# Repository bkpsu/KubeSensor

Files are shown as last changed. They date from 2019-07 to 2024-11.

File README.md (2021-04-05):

# KubeSensor
Kube - A modular, expandable home automation multi sensor platform

## Description

The Kube V2 builds on the previous [design](https://www.thingiverse.com/thing:2539897), incorporating improvements to modularity, support for additional sensors, and building ease.

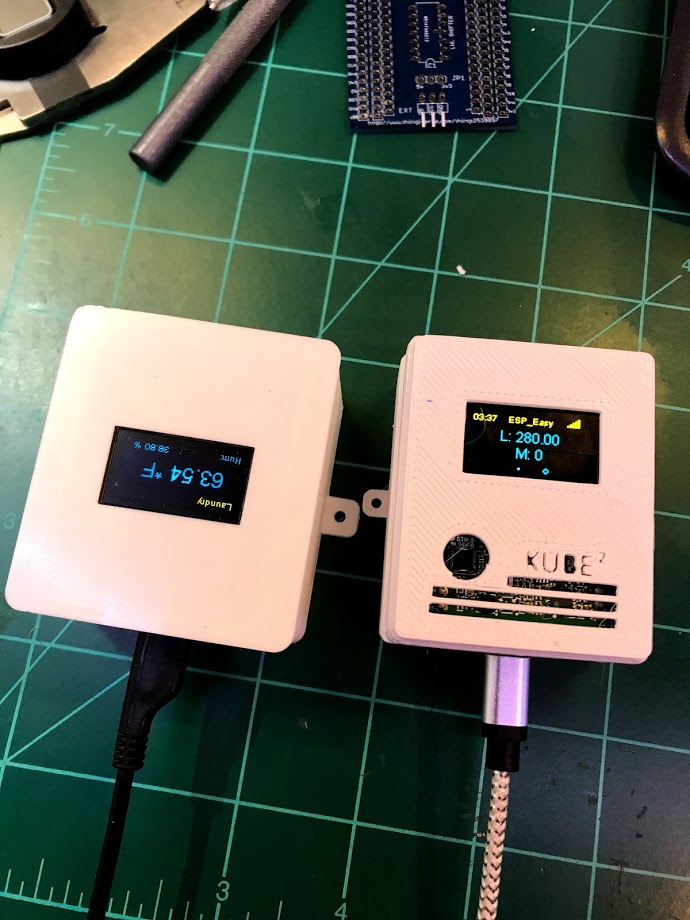
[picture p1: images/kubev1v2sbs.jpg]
    

##### Original Kube (left) and Kube V2 (right)

The main design improvement for Kube V2 is that all components are installed on dedicated PCBs, removing the need for wiring, and the PCBs are connected to each other via long headers, which allow the different "modules" to snap together to form a complete Kube.

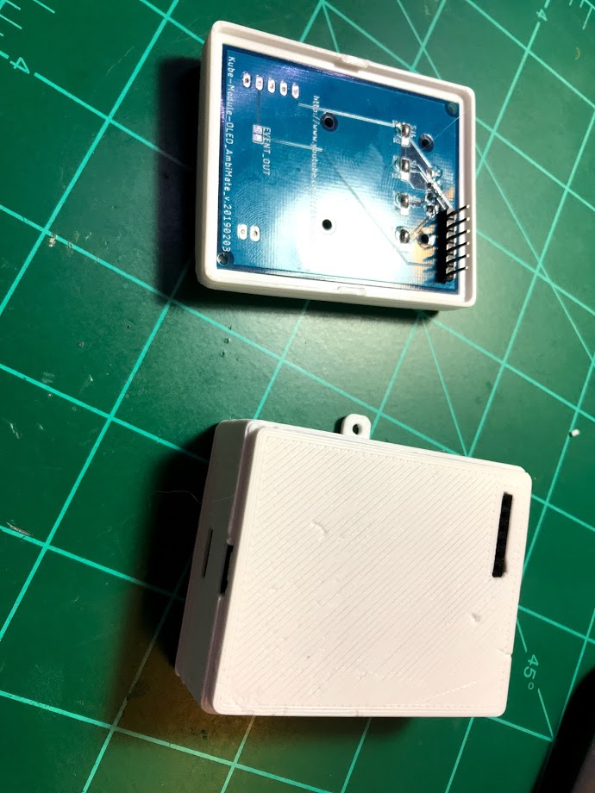
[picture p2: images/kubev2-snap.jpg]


##### OLED module (top) with male headers that snap into the base board (bottom) with tabs on the 3d printed enclosures holding the module in place

The 6-pin header is populated with I2C signals from the NodeMCU (D1/D2), D4 pin for LED control, and 5V and 3V3 power supply pins with ground. This allows building various different designs of the "stack", and future expansion of the Kube platform, via I2C connected "submodules". The design currently contains four modules, including:

1. Base module (with NodeMCU, breakout headers, 74HCT125N level shifter and external connectors/spots for DHT22 sensor)
2. Power Supply module (with AC/DC, DC/DC and POE-level power supply options, to provide the 5V power for the stack)
3. Analog/Digital IO module (offering expansion of Digital I/O up to 128 signals and 4 channels of 16-bit ADC analog)
4. OLED/AmbiMate sensor module (offering a 0.96" OLED screen for local sensor data display and support for the multiple sensor AmbiMate MS4 board from TE Connectivity)

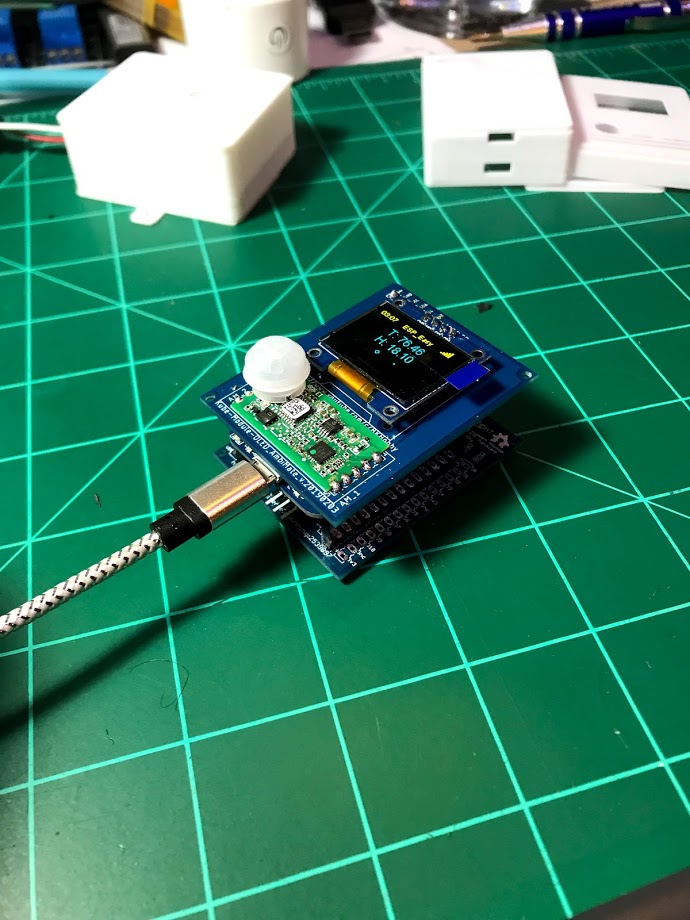
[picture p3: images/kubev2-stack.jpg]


##### Kube stack with boards 1 (Base Module) and 4 (OLED/AmbiMate) shown, comprising a multi sensor

The different boards can be stacked in any order (with OLED board on top, of course), and multiple ADIO boards can be stacked together to expand I/O up to 128 channels.

The Kube v2 supports typical ESP8266 firmwares, including [ESPEasy](https://www.letscontrolit.com/wiki/index.php?title=ESPEasy), as well as my original Kube [firmware](https://github.com/bkpsu/NodeMCU-Home-Automation-Sensor) (with minor changes for pin layout). With ESPEasy, the different sensors and OLED screen can be easily connected to home automation platofrms like [openHAB](https://www.openhab.org) or [HomeAssistant](https://www.home-assistant.io/) via MQTT.

---

## Boards

This section will describe the currently available Kube module boards in detail, including schematics and any jumper settings required for each board, as well as links to the parts required to build each module.

### 1. Kube Base Module

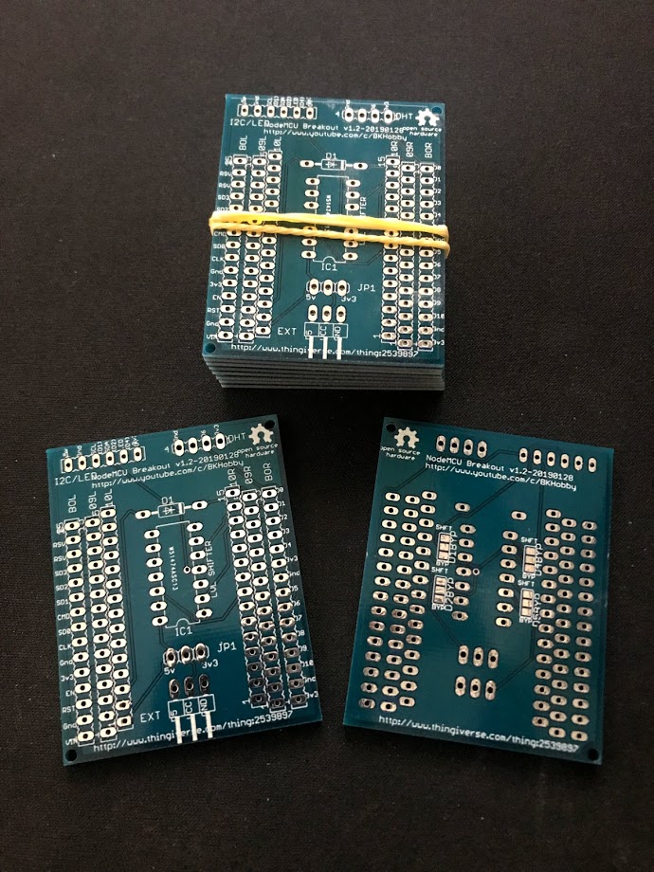
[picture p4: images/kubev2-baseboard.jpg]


The Kube Base module is the only **required** board in the Kube stack. It contains the headers for a [NodeMCU](https://amzn.to/2l9GGET) v0.9, v2 (LoLin v3 works, but won't fit the enclosure), as well as breakout headers for all of the NodeMCU pins. With just the Kube Base module, a NodeMCU, a DHT22 sensor, and an OLED screen, you can create [this sensor](https://www.thingiverse.com/thing:2539897):

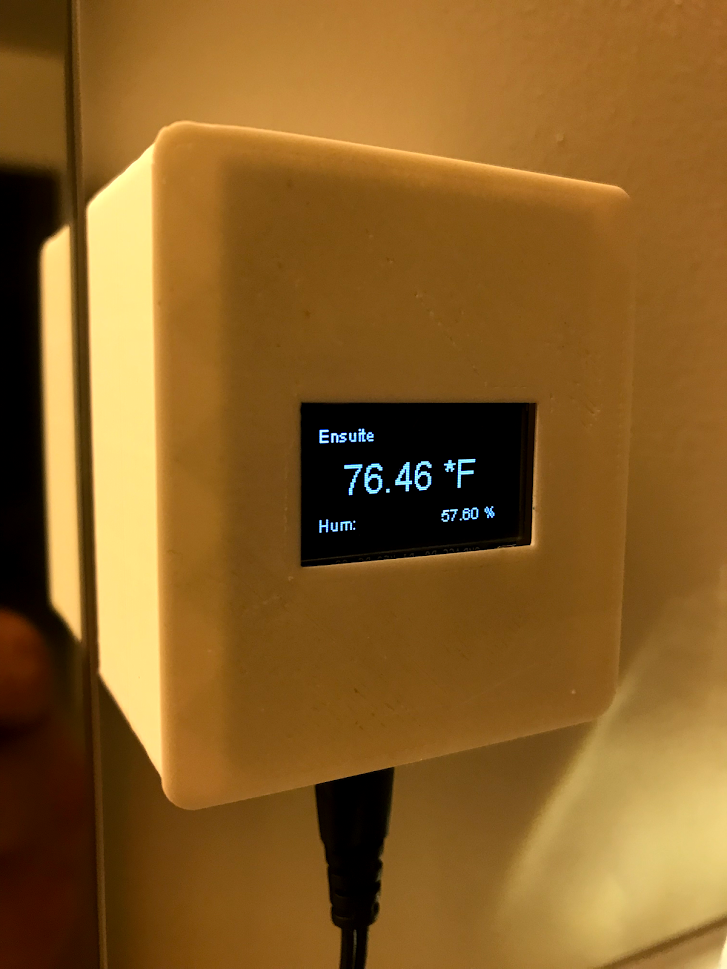
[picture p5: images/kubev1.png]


The base module contains the following features/headers:

**TOP**: (NodeMCU side)

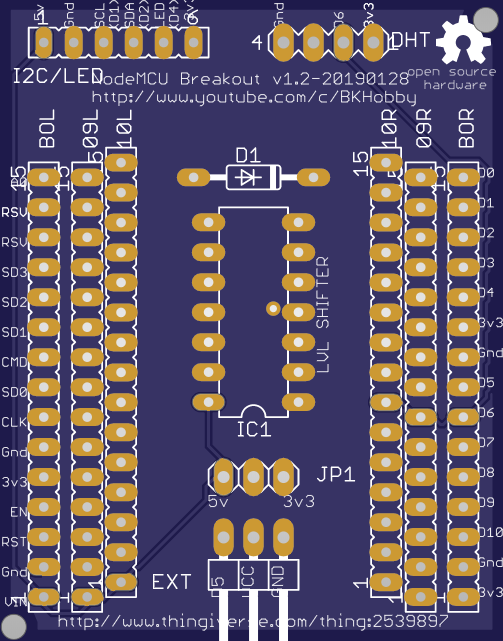
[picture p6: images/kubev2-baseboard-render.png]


|Device|Usage|Notes|
|:---|:-----|---|
|EXT|Used for external sensor connections, e.g. [HC-SR501](https://amzn.to/2l9G0zl) PIR motion sensor (D5 NodeMCU pin)|VCC pin is tied to JP1, sourcing either 3.3V or 5V DC|
|JP1|Selects 5V or 3.3V supply voltage for the EXT header|Does *not* affect D5 pin voltage range|
|IC1|[74HCT125N](https://amzn.to/2l9FBwP) 4-channel fast level shifter|Used for I2C/LED and EXT signal pins; Great for LED pixels|
|D1|[BAT43](https://amzn.to/2jFCRqv) Schottky Diode|Used between RST and D0 pins on the NodeMCU to prevent boot-up issues during flashing|
|DHT|[DHT22](https://amzn.to/2l98yZL) Temperature/Humidity sensor|Used when base baord is used as a remote temperature/humidity sensor; uses D6 pin on NodeMCU|
|I2C/LED|I2C bus connector header, to allow *daughter-boards* to connect to the Kube base board and to each other|Has both 5V and 3.3V pins, GND, SCL (D1) and SDA (D2), as well as an additional digital I/O pin (D4), commonly used in LED strip controller firmware|

**BOTTOM**:

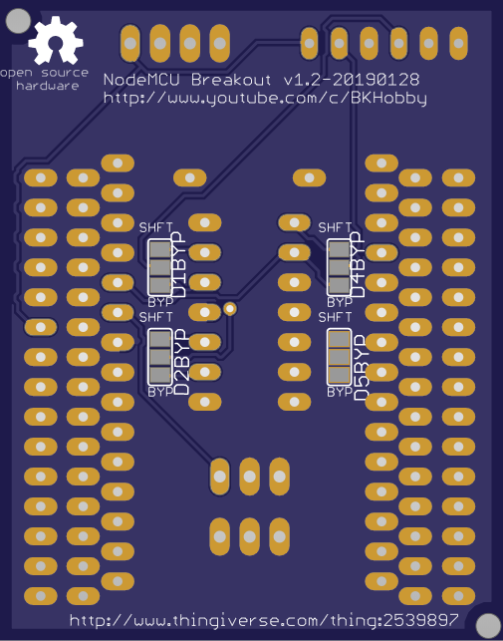
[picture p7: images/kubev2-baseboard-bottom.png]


|Device|Usage|Notes|
|:---|:-----|---|
|D1BYP, D2BYP|Used to shift (to 5V via IC1) or bypass (3.3V from the NodeMCU) the I2C Clock (D1, SCL) and Data (D2, SDA) pins within the I2C/LED header|Solder middle pad to either the SHFT (for 5V) or BYP (for 3.3v) pads.|
|D4BYP|Used to shift (to 5V via IC1) or bypass (3.3V from the NodeMCU) the D4 LED pin within the I2C/LED header|Solder middle pad to either the SHFT (for 5V) or BYP (for 3.3v) pads.|
|D5BYP|Used to shift (to 5V via IC1) or bypass (3.3V from the NodeMCU) the D5 EXT pin within the EXT sensor header|Solder middle pad to either the SHFT (for 5V) or BYP (for 3.3v) pads.|

The full schematic for the Kube baseboard is shown below: 

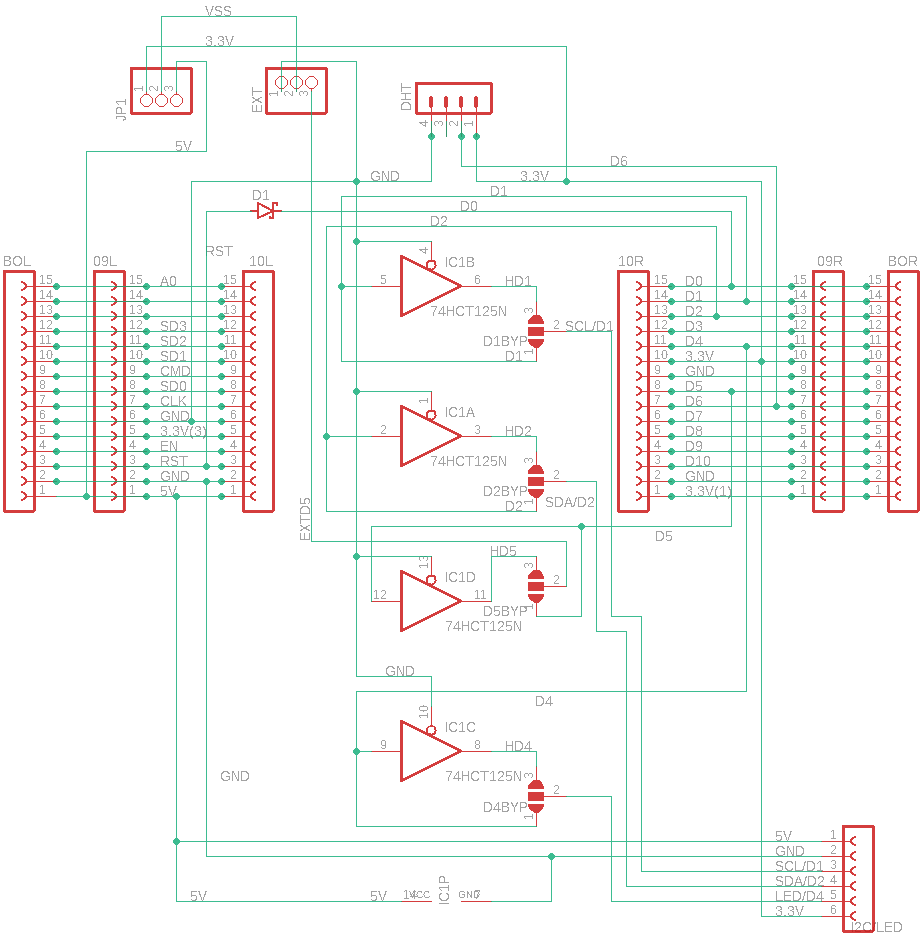
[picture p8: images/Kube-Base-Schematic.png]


### 2. Power Supply Module

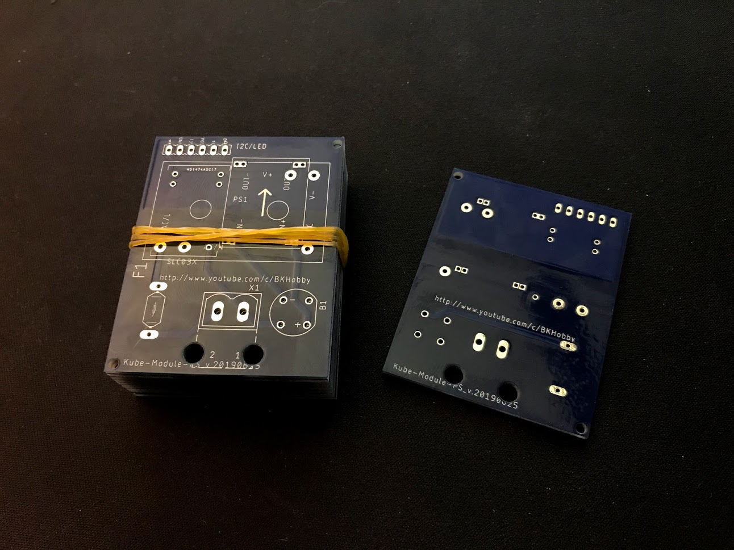
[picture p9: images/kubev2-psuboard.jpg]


The Kube Power supply submodule offers several options to provide the 5VDC power required to run the NodeMCU and the entire Kube stack. It is *generally* not required, since it's perfectly fine to power the Kube with just a USB power supply via the NodeMCU's micro-USB port (accessible via a hole in the base module's enclosure), but if you're going to use more sensors, IO boards, or other external devices, it *is recommended* to supply power to the Kube stack via this PSU board module.

The Kube PS board module provides three possible configurations, each allowing different input voltages, with 5V DC output.

1. Using a [MeanWell IRM-03-5](https://amzn.to/2lbSsym) AC/DC power supply (110VAC in, 5VDC out) for a wall-pluggable unit
2. Using [MeanWell SLC03x](https://www.arrow.com/en/products/slc03b-05/mean-well-enterprises) series DC-DC power supplies for multiple input options (12j/24VDC, Power-over-Ethernet, etc)
3. Using a [Rectifier](https://amzn.to/2lin9SL) and a [Buck Converter](https://amzn.to/2lkQhZH) to convert low-voltage AC (e.g. a door bell transformer or HVAC thermostat power) to power the kube stack.

***NOTE***: **BE EXTREMELY CAREFUL WHEN USING THE KUBE PS MODULE WITH AC POWER. THE PCB TRACES ON THE BOTTOM OF THE BOARD WILL HAVE LIVE AC VOLTAGE ON THEM. IT IS BEST TO KEEP THE UNIT UNPLUGGED WHILE ASSEMBLING/DISSASEMBLING THE KUBE STACK.**

Regardless of which of the 3 power methods you're using, the power input wiring will go through the [2-pin screw terminal](https://amzn.to/2lhCMtC) (X1), with Line or DC+ on the left terminal, and Neutral or DC- on the right terminal. The line/DC+ line is [fuse-protected](https://amzn.to/2jPolfY) prior to going to the power supplies. Secure the input wiring with a zip-tie through the two holes drilled below the X1 connector.

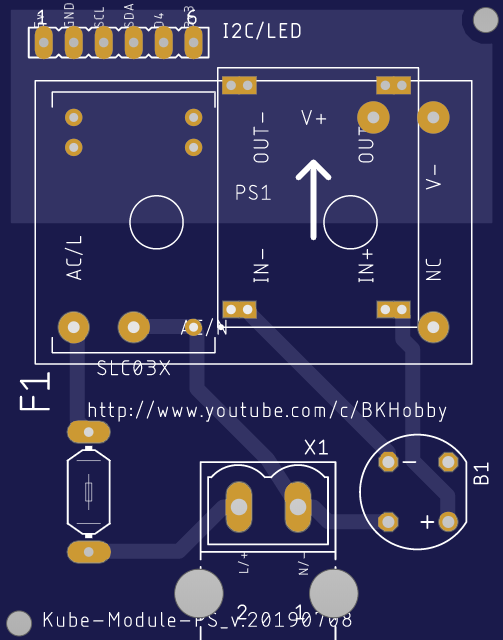
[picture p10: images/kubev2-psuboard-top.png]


The full schematic for the Kube Power Supply submodule is shown below:

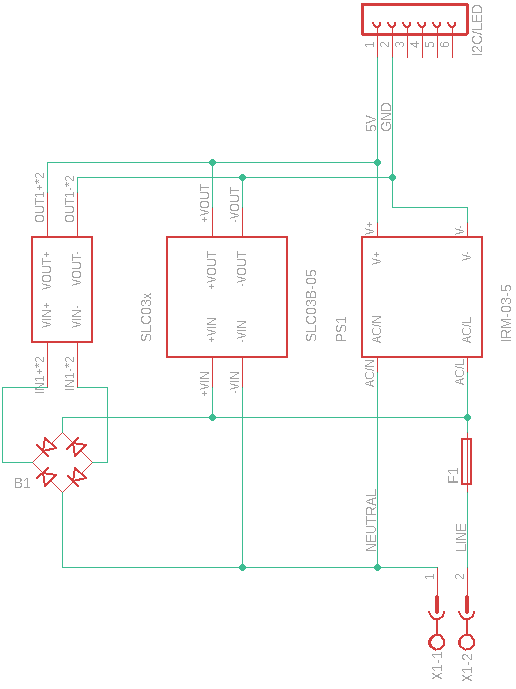
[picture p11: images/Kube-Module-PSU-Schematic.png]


### 3. Analog/Digital I/O module

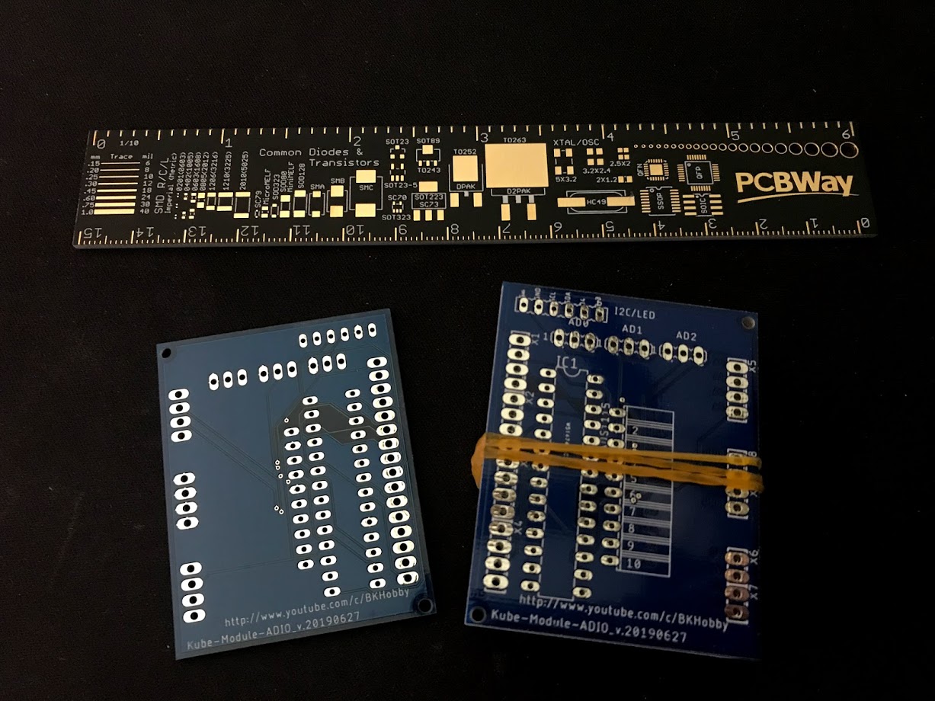
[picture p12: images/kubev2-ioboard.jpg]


The ADIO Kube submodule can be used when more I/O is required than the NodeMCU GPIO pins provide, or for a more precise way to bring in analog inputs into the Kube sensor.

The ADIO submodule provides space for the [MCP23017](https://amzn.to/2lg6Qpt) 16-channel digital I/O expander, as well as a [ADS1115](https://amzn.to/2lgUYDz) 4-channel 16-bit analog ADC module. In addition, the MCP23017 address pins have been broken out into three headers (AD0, AD1, AD2), which allow addressing up to 8 different MCP23017 chips. In theory, you could stack 8 ADIO submoodules in the Kube stack, for a total of 128 digital I/O pins!

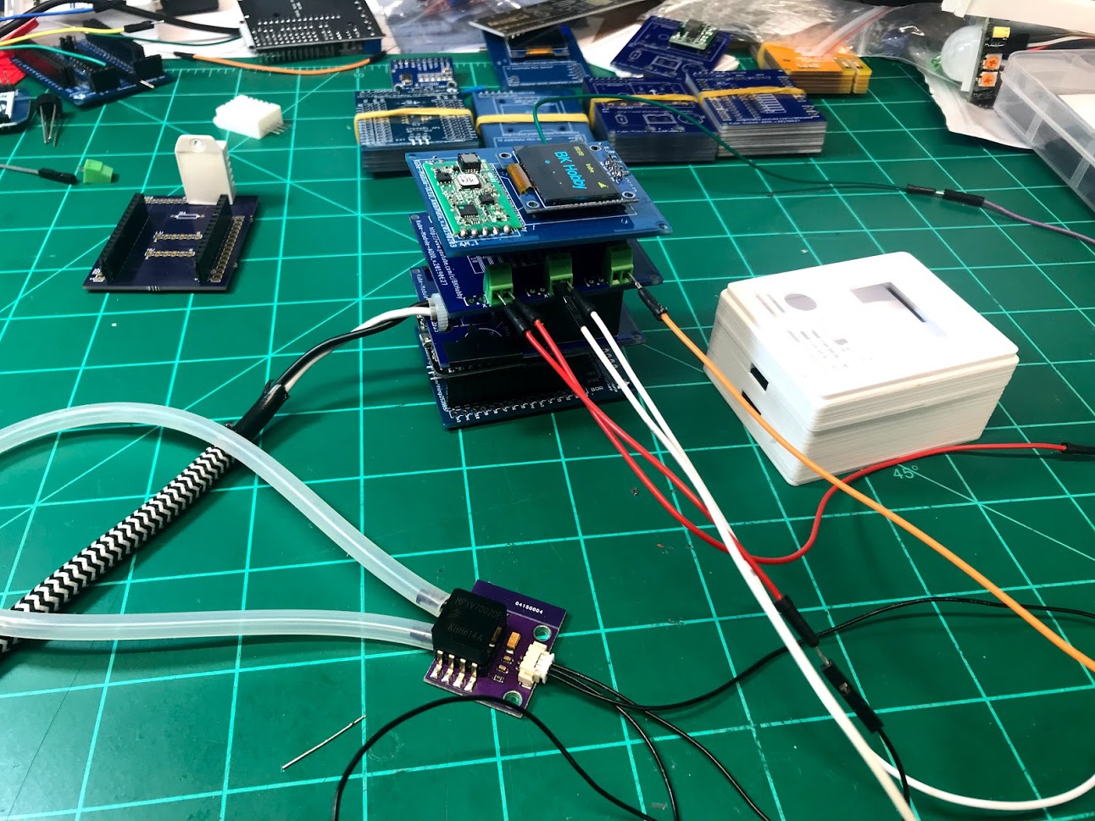
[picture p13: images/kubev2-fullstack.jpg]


##### Testing a full Kube stack with an analog differential pressure sensor connected to the ADIO submodule.

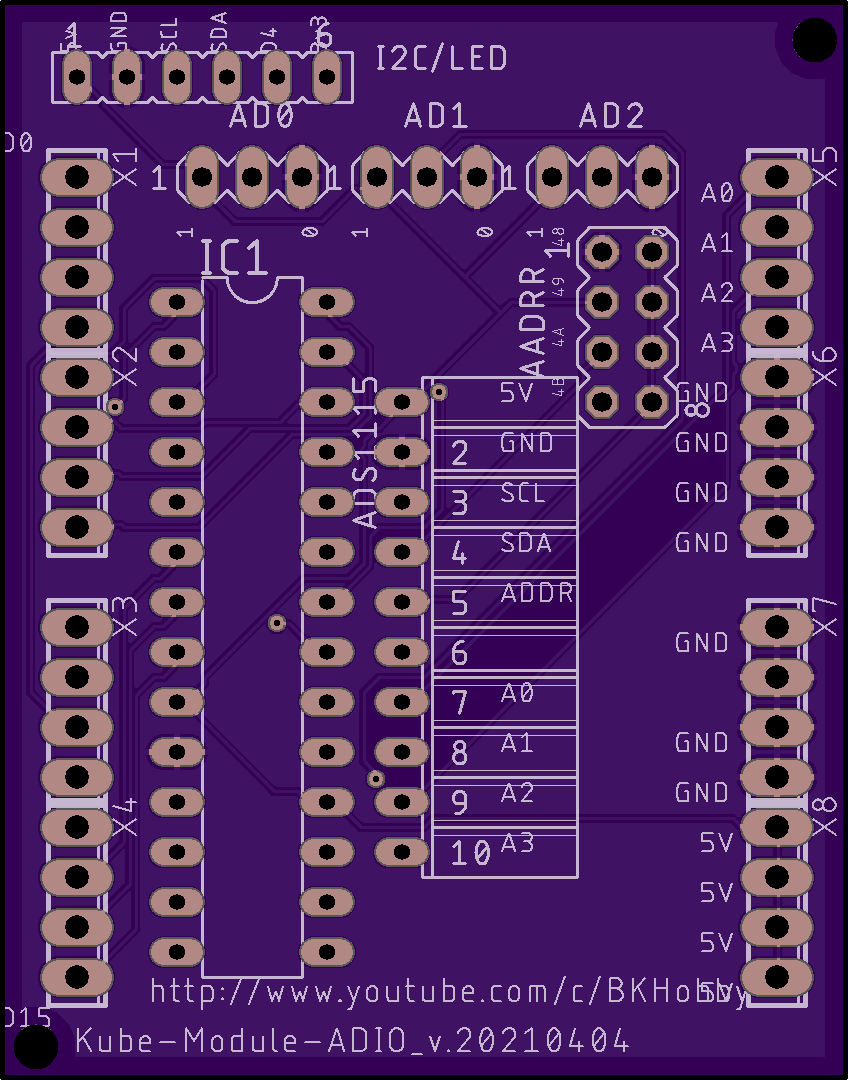
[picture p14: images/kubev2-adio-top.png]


The MCP23017 addressing is handled via jumpers on the AD0, AD1 and AD2 headers. Jumpering the left pin to the middle pin sets that address bit HIGH (1) and jumpering the right pin to the middle pin sets it LOW (0). The following table shows the complete I2C address scheme based on jumper settings:

|AD0|AD1|AD2|I2C Address|
|---|---|---|-----|
|0|0|0|0x20|
|1|0|0|0x21|
|0|1|0|0x22|
|1|1|0|0x23|
|0|0|1|0x24|
|1|0|1|0x25|
|0|1|1|0x26|
|1|1|1|0x27|

The ADS1115 board is also addressable, using the AADDR headers. Select addresses 0x48, 0x49, 0x4A or 0x4B by placing a jumper across one set of the jumper pins. This way, up to 4 ADIO submodules may have ADS1115 breakouts installed, for a total of 16 analog input channels.

The rest of the devices on the ADIO submodule are described below:

|Device|Usage|Notes|
|:---|:-----|---|
|IC1|[MCP23017](https://amzn.to/2lg6Qpt) I/O Expander|16 channel digital I/O expander|
|ADS1115|[ADS1115](https://amzn.to/2lgUYDz)|4 channel 16-bit analog ADC module (can also use [ADS1015](https://amzn.to/2lcyVOj), 12-bit ADC)|
|X1|Channels 1 through 4 (top to bottom) of the MCP23017|Wired in using [4-pin screw terminals](https://amzn.to/2lc5hbY)|
|X2|Channels 5 through 8 (top to bottom) of the MCP23017|Wired in using [4-pin screw terminals](https://amzn.to/2lc5hbY)|
|X3|Channels 9 through 12 (top to bottom) of the MCP23017|Wired in using [4-pin screw terminals](https://amzn.to/2lc5hbY)|
|X4|Channels 13 through 16 (top to bottom) of the MCP23017|Wired in using [4-pin screw terminals](https://amzn.to/2lc5hbY)|
|X5|Channels 1 through 4 (top to bottom) of the ADS1115|Wired in using [4-pin screw terminals](https://amzn.to/2lc5hbY)|
|X6 & X7|GND terminals for the I/O signals|Wired in using [4-pin screw terminals](https://amzn.to/2lc5hbY)|
|X8|5V power terminals for the I/O signals|Wired in using [4-pin screw terminals](https://amzn.to/2lc5hbY)|
|I2C/LED|I2C bus connector header, to allow *daughter-boards* to connect to the Kube base board and to each other|Has both 5V and 3.3V pins, GND, SCL (D1) and SDA (D2), as well as an additional digital I/O pin (D4), commonly used in LED strip controller firmware|

The full schematic for the Kube IO submodule is shown below:

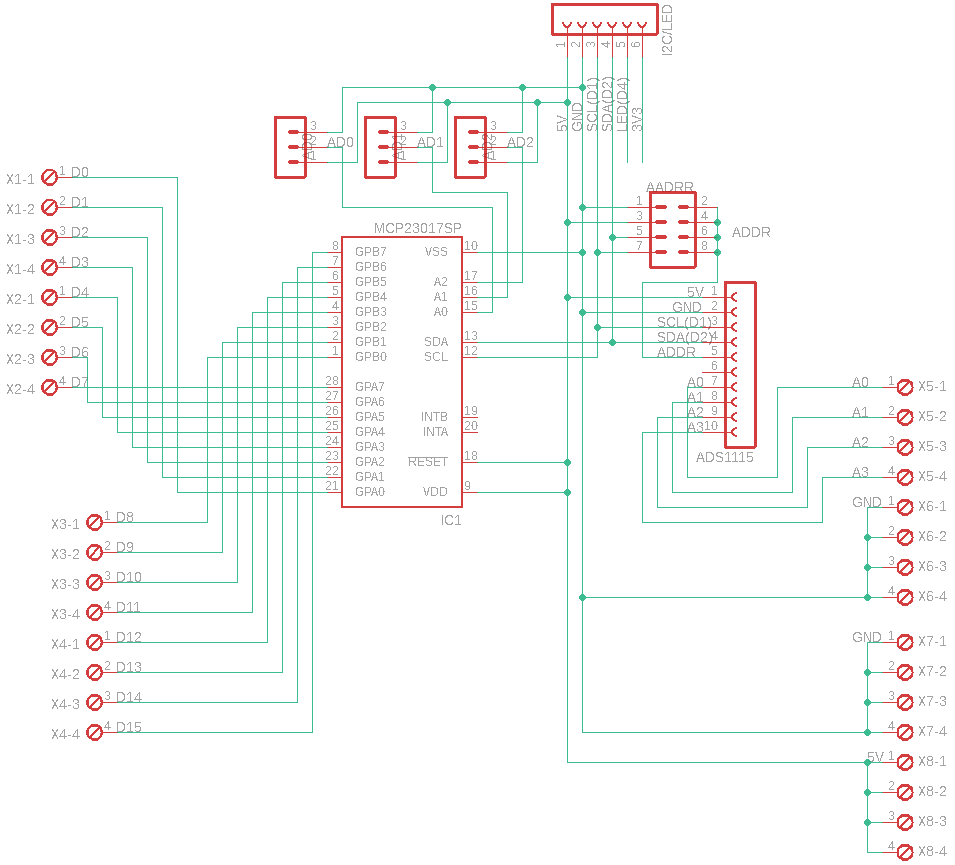
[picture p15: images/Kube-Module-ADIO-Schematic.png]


### 4. OLED/AmbiMate MS4 module

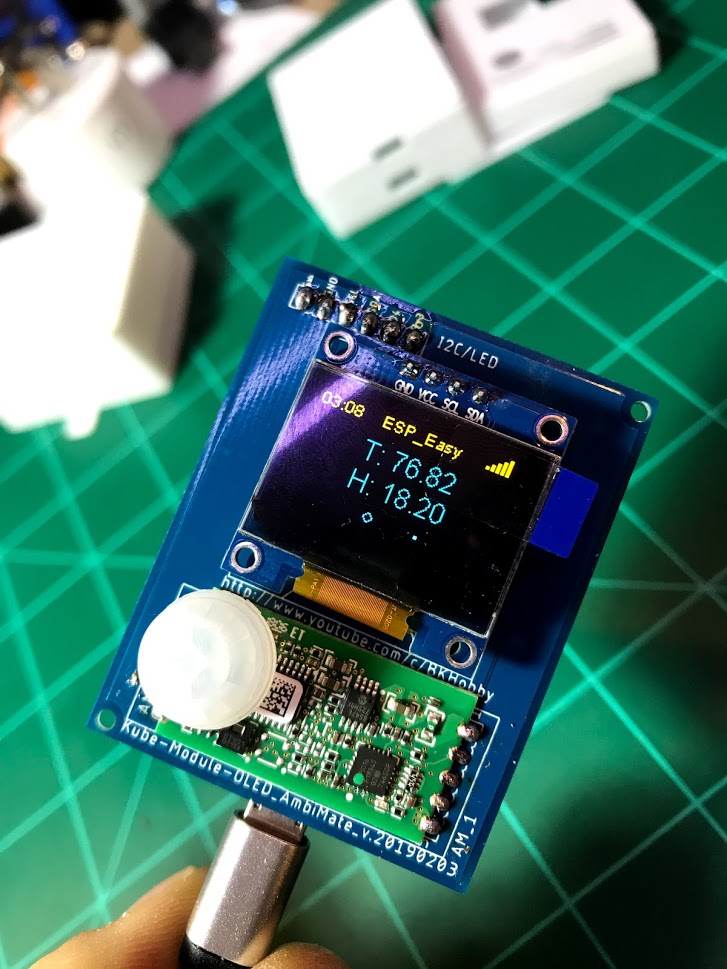
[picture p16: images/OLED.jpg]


The OLED/AmbiMate submodule serves a dual purpose. It can provide a local display of all the Kube sensor values (if the OLED screen is installed), and with the optional TE AmbiMate MS4 sensor board installed, it can read values such as temperature/humidity/light/audio level/motion/CO2 level/VOCs level, and provide them via I2C to the NodeMCU. In lieu of the TE Ambimate MS4, a space is provided for the cheaper (but still very precise) BME280/BMP280 sensor board.

The [OLED display](https://amzn.to/2ll4BkL) used (0.96") provides a good canvas for displaying local sensor data. However, the boards used with these displays are not always standard. I have seen multiple versions of these boards, with different pinouts for the 4 pin i2C interface, e.g. GND/VCC/SCL/SDA or VCC/GND/SCL/SDA. To allow both boards to be installed on the submodule, there are 4 jumpers on the back of the board, that allow swapping of the GND/VCC pins, and SCL/SDA pins, to hopefully match any combination of pins on the widely available modules.

The devices that fit on this board are as follows:

**TOP**:

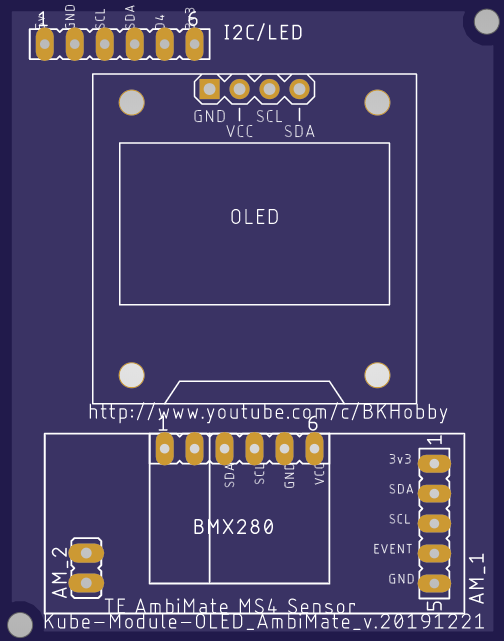
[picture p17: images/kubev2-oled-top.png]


|Device|Usage|Notes|
|:---|:-----|---|
|OLED|[OLED 0.96" Display](https://amzn.to/2ll4BkL)|16 channel digital I/O expander|
|TE AmbiMate MS4 Sensor|[Full Version](https://www.arrow.com/en/products/2316852-2/te-connectivity) or [Base Version](https://www.arrow.com/en/products/2316851-1/te-connectivity) (Temp/Humidity/Light/Motion only)|Multi-sensor from TE, with temperature/humidity/motion/light/CO2/VOCs and audio level measurements|
|I2C/LED|I2C bus connector header, to allow *daughter-boards* to connect to the Kube base board and to each other|Has both 5V and 3.3V pins, GND, SCL (D1) and SDA (D2), as well as an additional digital I/O pin (D4), commonly used in LED strip controller firmware|
|BMX280|[BME280/BMP280](https://amzn.to/2ZcHmcq) I2C sensor connector header|Jumper SJ5 to correct VCC (3v3 or 5V) for your sensor|

**BOTTOM**:

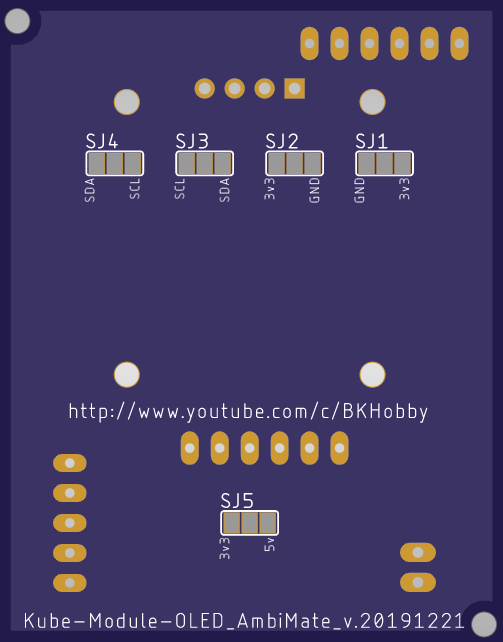
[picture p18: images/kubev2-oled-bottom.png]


|Device|Usage|Notes|
|:---|:---|---|
|SJ1|First OLED pin selector|Match GND or VCC with your OLED screen's first pin, and solder that side to the middle pad|
|SJ2|Second OLED pin selector|Match GND or VCC with your OLED screen's second pin, and solder that side to the middle pad|
|SJ3|Third OLED pin selector|Match SCL or SDA with your OLED screen's third pin, and solder that side to the middle pad|
|SJ4|Fourth OLED pin selector|Match SCL or SDA with your OLED screen's fourth pin, and solder that side to the middle pad|
|SJ5|BMx280 sensor VCC selector|If using the 4-pin (5V) unit, jumper middle pad to 5v pad, and for 6-pin (3v3) unit, jumper middle pad to 3v3 pad|

The full schematic for the Kube OLED/AmbiMate submodule is shown below:

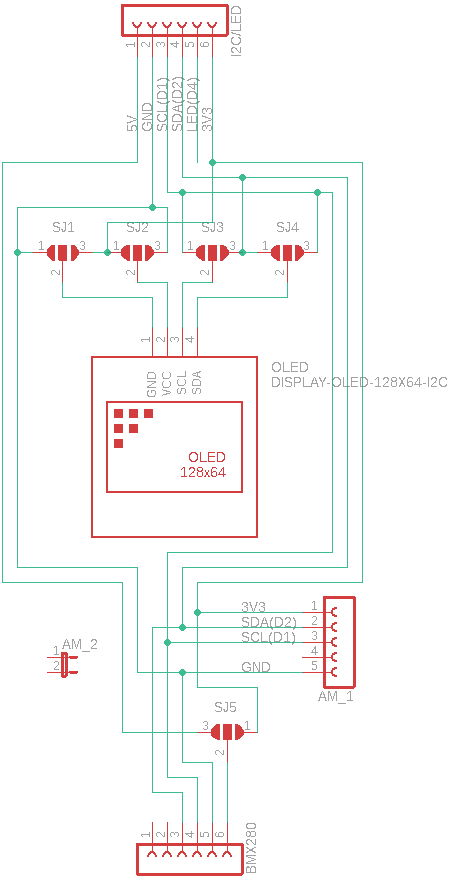
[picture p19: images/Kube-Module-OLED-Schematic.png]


---

## Software

Use [ESPEasy](https://www.letscontrolit.com/espeasy/) firmware to easily connect the different sensors to the NodeMCU, and send them to your favorite database, or home automation program.

---

## BOM

Full, up to date BOM is available [here](Kube_V2_BOM.xlsx).

Get the PCB Boards directly from [PCBWay](https://www.pcbway.com/project/member/?bmbno=74C10494-455E-47)!

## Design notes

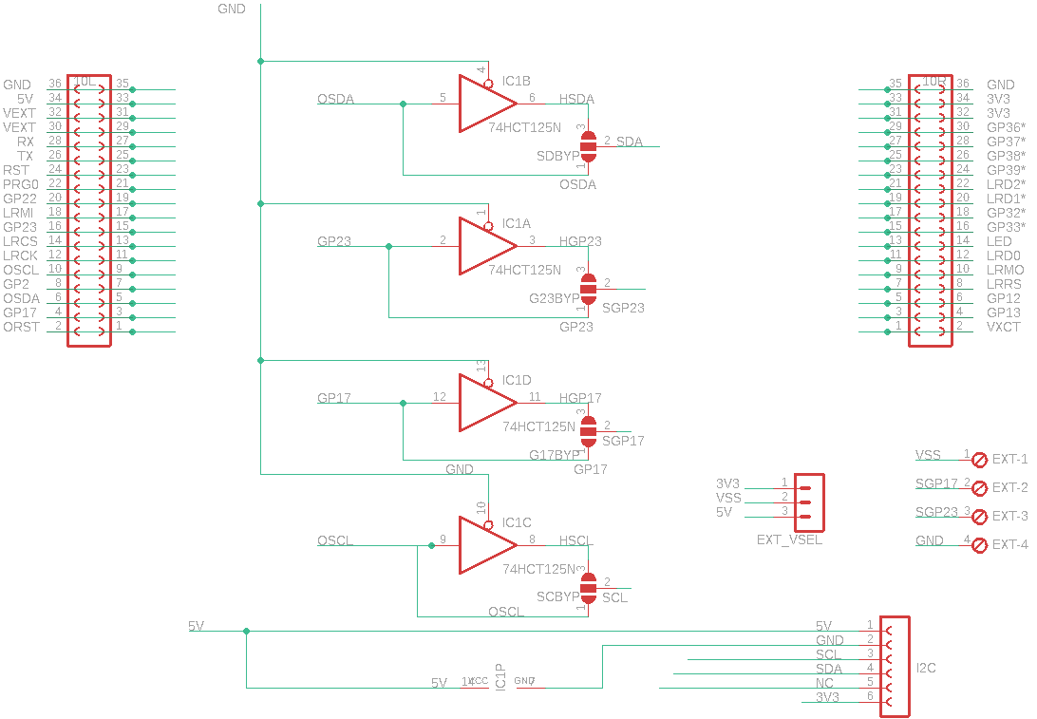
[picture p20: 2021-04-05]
Kube_Base_Heltec_WifiLoRaV3/schematic.png

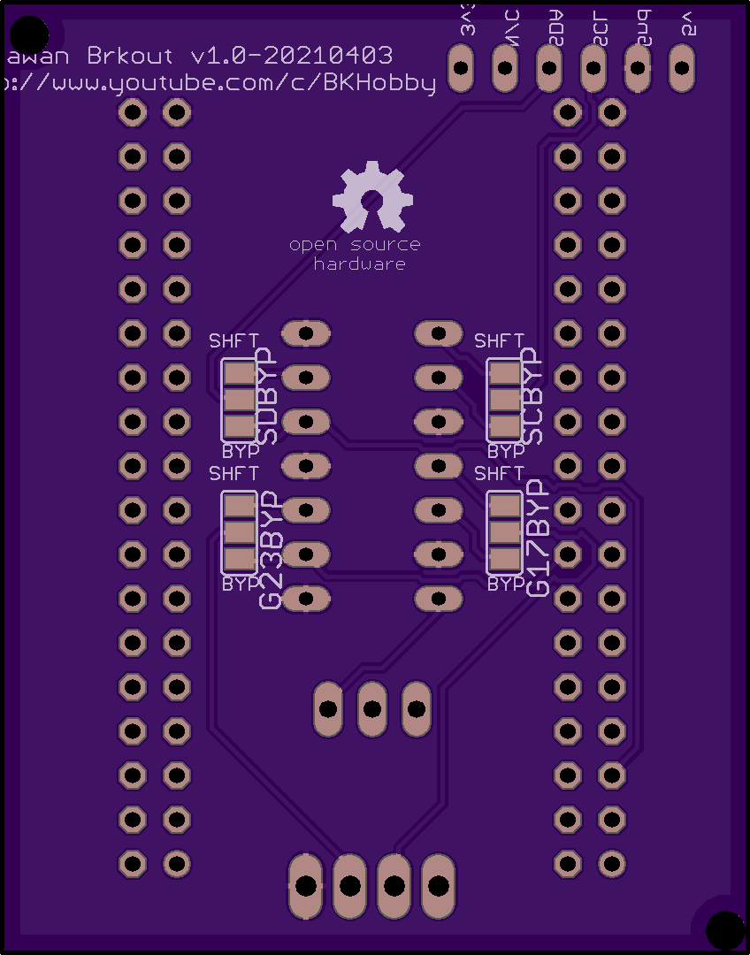
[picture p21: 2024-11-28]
images/kubev2-helteclorav2-bottom.png

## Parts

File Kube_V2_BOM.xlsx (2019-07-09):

BK Hobby Kube V2 Parts list
Required Parts Below
Component | Link | Number needed for one Kube
NodeMCU | https://amzn.to/2YEUlTc | 1
Headers | https://amzn.to/2EgvnSs | 1
DHT22 Sensor | https://amzn.to/2xyVRKP | 3
Schottky Diodes | https://amzn.to/2E5nr6n | 1
Level Shfiter (74HCT125N) | https://amzn.to/2Xz70uv | 1
OLED Screen | https://amzn.to/30gFxdO | 1
Dupont Wires | https://amzn.to/2JuLmNY | 1
Jumper Headers | https://amzn.to/2Jvkg9t | 1
TE Sensor on OLED Board | https://www.arrow.com/en/products/2316851-1/te-connectivity | 1
Long Male Headers (for OLED board) | https://amzn.to/2GR4pT7 | 1
Long Female Header (for IO and PS boards) | https://amzn.to/2S0L7y8 | 1
ADS1115 boards for analog input | https://amzn.to/2XxGVM4 | 2
4-pin PCB screw terminal connector (for IO board) | https://amzn.to/2XvnzHN | 1
Rectifiers (for PS board) | https://amzn.to/2XyBIUn | 1
Glass fuses (for PS board) | https://amzn.to/2xCBYCk | 1
DC-DC buck converter (PS board) | https://amzn.to/30dXgCC | 1
5 mm pitch screw terminal for PCB (PS board) | https://amzn.to/2FYl4CU | 1
MCP23017 IO expanders | https://amzn.to/2S01Otl | 1
Optional hardware
WS2812 RGB LEDs | https://amzn.to/2XxdQ3x | Optional

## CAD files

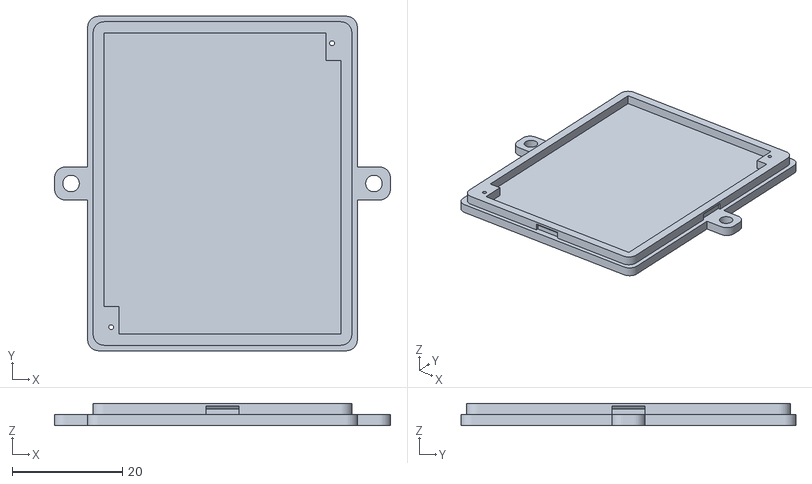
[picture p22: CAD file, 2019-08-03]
Kube_Base_ESP32_HiLetGo/Kube_ESP32HLG_Module_Enclosure_Cover.stl
60.9 x 60.6 x 4.00

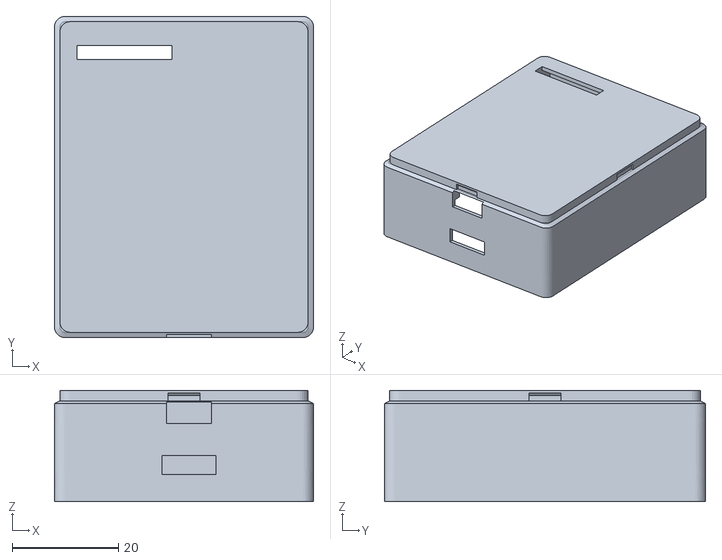
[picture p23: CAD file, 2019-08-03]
Kube_Base_NodeMCU/Kube_Base_Module_Enclosure.stl
48.9 x 60.6 x 21.0

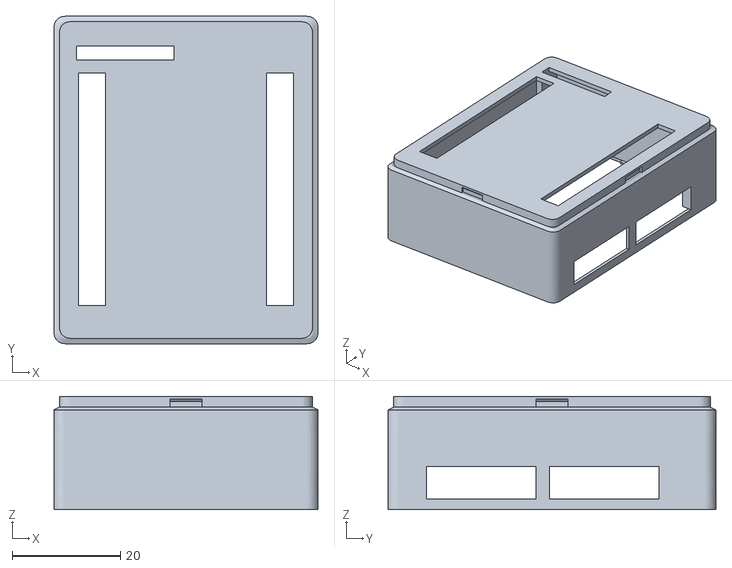
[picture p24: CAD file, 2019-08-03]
Kube_Module_ADIO/Kube-Module-ADIO.stl
48.9 x 60.6 x 21.0

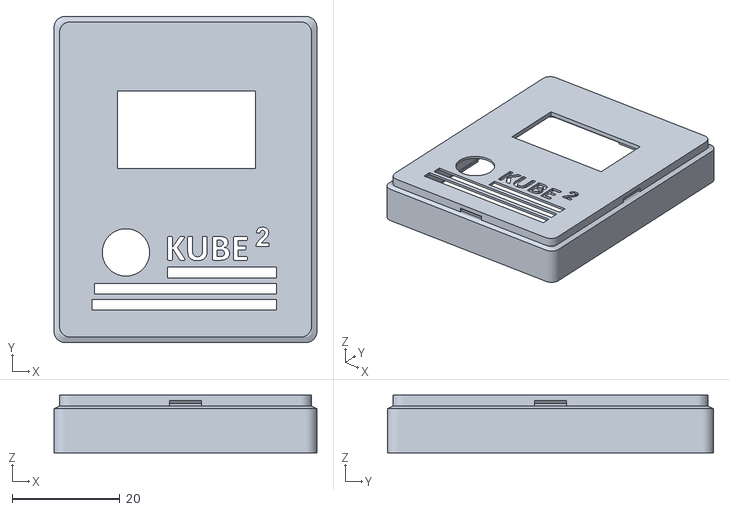
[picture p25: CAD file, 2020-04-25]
Kube_Module_OLED_AmbiMate/Kube_Module_OLED_AmbiMate.stl
48.9 x 60.6 x 10.7

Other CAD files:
Kube_Module_PS/Kube-Module-PSU.stl
Kube_Base_ESP32_HiLetGo/Enclosure-ESP32HLG.f3d
Kube_Base_ESP32_HiLetGo/Enclosure-Rear-Cover.f3d
Kube_Base_Heltec_WifiLoRaV2/Enclosure-LoRaWAN.f3d
Kube_Base_Heltec_WifiLoRaV2/Enclosure-Rear-Cover.f3d
Kube_Base_Heltec_WifiLoRaV3/Enclosure-LoRaWAN.f3d
Kube_Base_Heltec_WifiLoRaV3/Enclosure-Rear-Cover.f3d
Kube_Base_NodeMCU/Enclosure-Base.f3d
Kube_Base_NodeMCU/Enclosure-Rear-Cover.f3d
Kube_Module_ADIO/Kube-Submodule-ADIO.f3d
Kube_Module_OLED_AmbiMate/Kube-Module-Enclosure-Submodule-OLED.f3z
Kube_Module_PS/Kube-Submodule-PSU.f3d

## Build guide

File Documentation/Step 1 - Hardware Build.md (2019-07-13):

# Kube Multisensor V2 Hardware assembly
The BK Hobby Multisensor Kube v2 looks to build on the original platform.  The new design is modular enabling modification and application in a variety of use cases, and shortening build time.

The Kube V2 Multisensor is based on an extremely accurate TE multisensor that performs better than anything I could find.
# Step - by - Step 

Kube V2 Live stream 5 Prototype and tinkering 25:30 starts the build (http://www.youtube.com/watch?v=eWV52eQ6LFQ)

# **Step 1**

Start with the screen module.  Solder OLED screen into PCB.  The board contains 4 soldering bridges.  Attach the pins from the screen to the matching bridge locations.  Trim long pins from back of OLED screen once solder joint looks good. ~28 min youtube vid.

# **Step 2**

Connect the TE Connectivity AmbiMate sensor below the OLED Screen.  Start with the 2 pin side of the board.  Melt the solder into the holes on the board then apply heat to the board and solder on the front of the board.

# **Step 3**

Attach pre programed NodeMCU with ESPEasy to the NodeMCU breakout board with headers attached.

# **Step 4**

Test fit case with NodeMCU boards to ensure fit.

# **Step 5**

Using extra long 5 pin female headers (19 mm or greater), stick the pins into the NodeMCU I2C holes on the top lefthand side of the board.  Solder the pins in from the back of the board.

# **Step 6**

Insert a 6 pin standard male header into the I2C pin holes.  Solder in from the front of the PCB.

# **Step 7**

Bypass level shifting if needed by soldering all the solder bridges together.

# **Step 8**

Stack the NodeMCU board and the OLED board to test fit.  Once fit looks good plug in unit to test functionality.  Make sure your power cable is plugged into a power source.

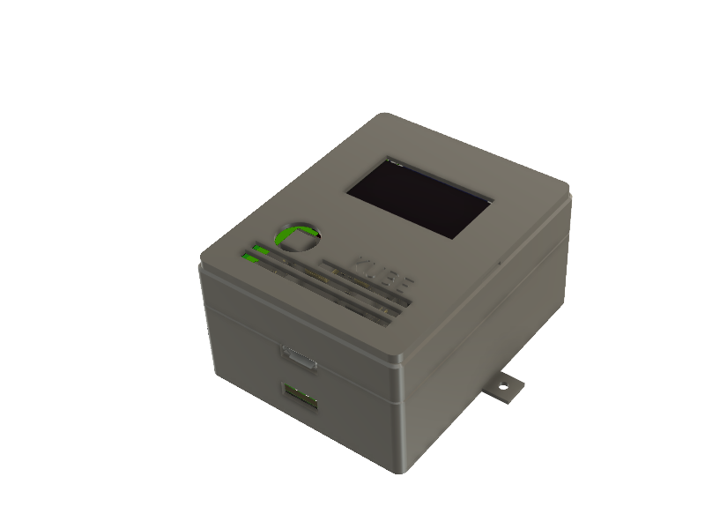
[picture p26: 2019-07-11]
images/Kube-Assembly.png

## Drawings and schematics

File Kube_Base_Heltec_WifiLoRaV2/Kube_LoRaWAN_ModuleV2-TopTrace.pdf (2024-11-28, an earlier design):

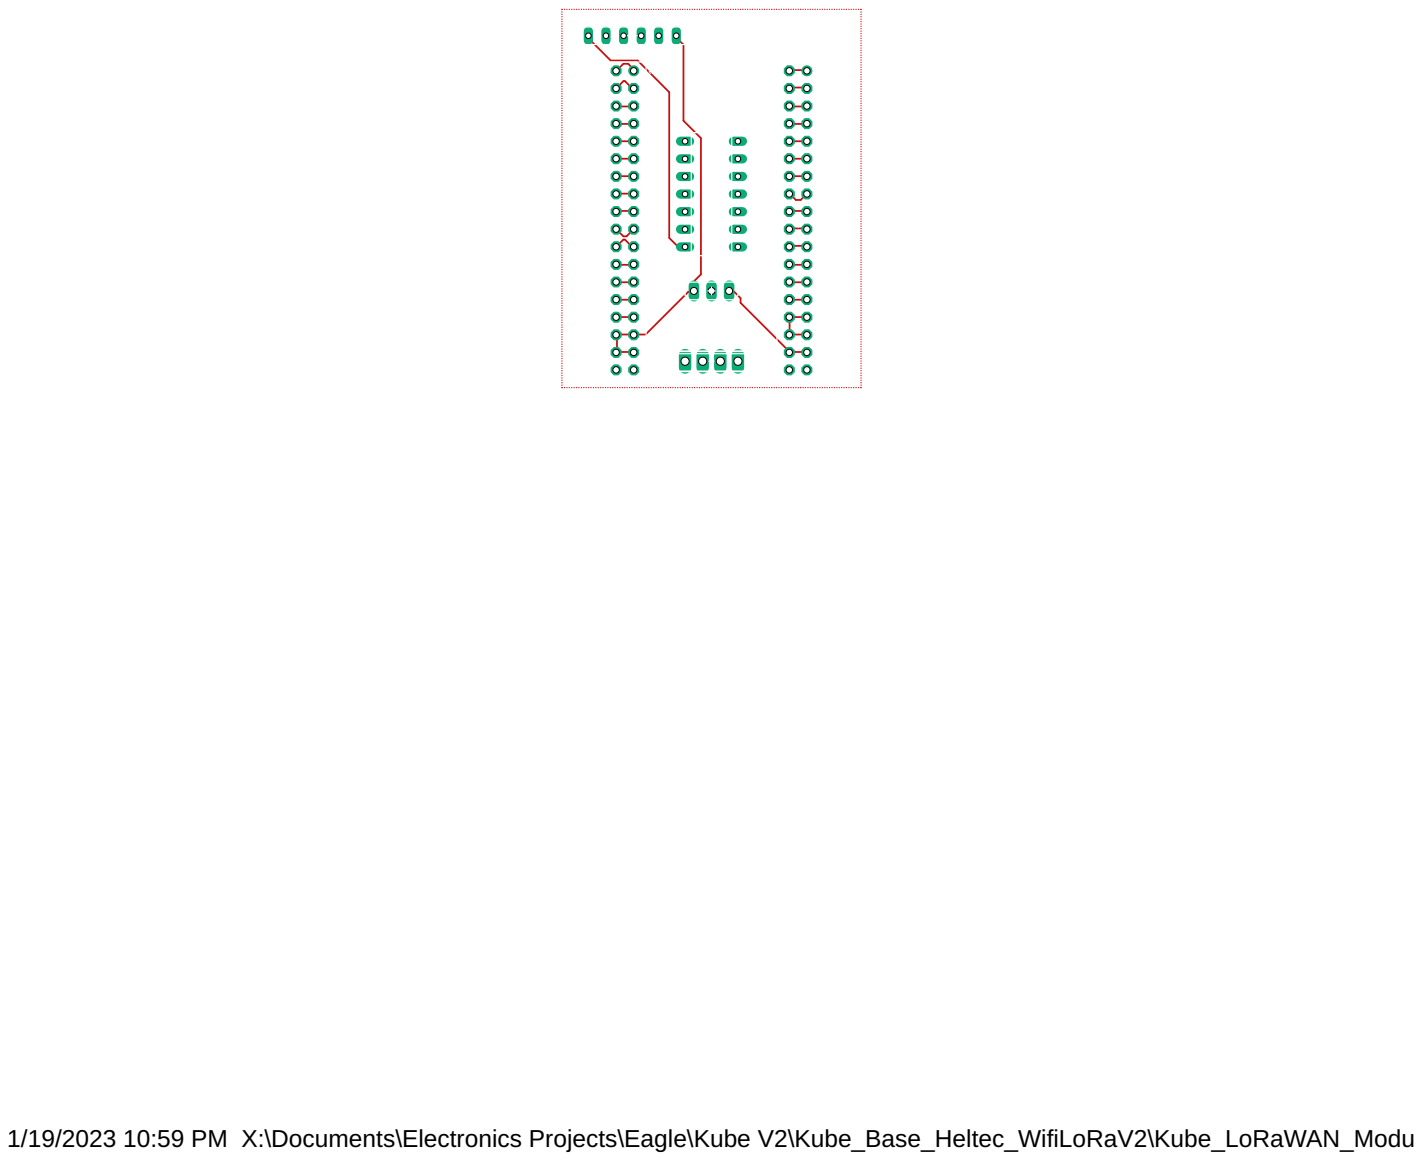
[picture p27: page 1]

1/19/2023 10:59 PM X:\Documents\Electronics Projects\Eagle\Kube V2\Kube_Base_Heltec_WifiLoRaV2\Kube_LoRaWAN_Module.brd

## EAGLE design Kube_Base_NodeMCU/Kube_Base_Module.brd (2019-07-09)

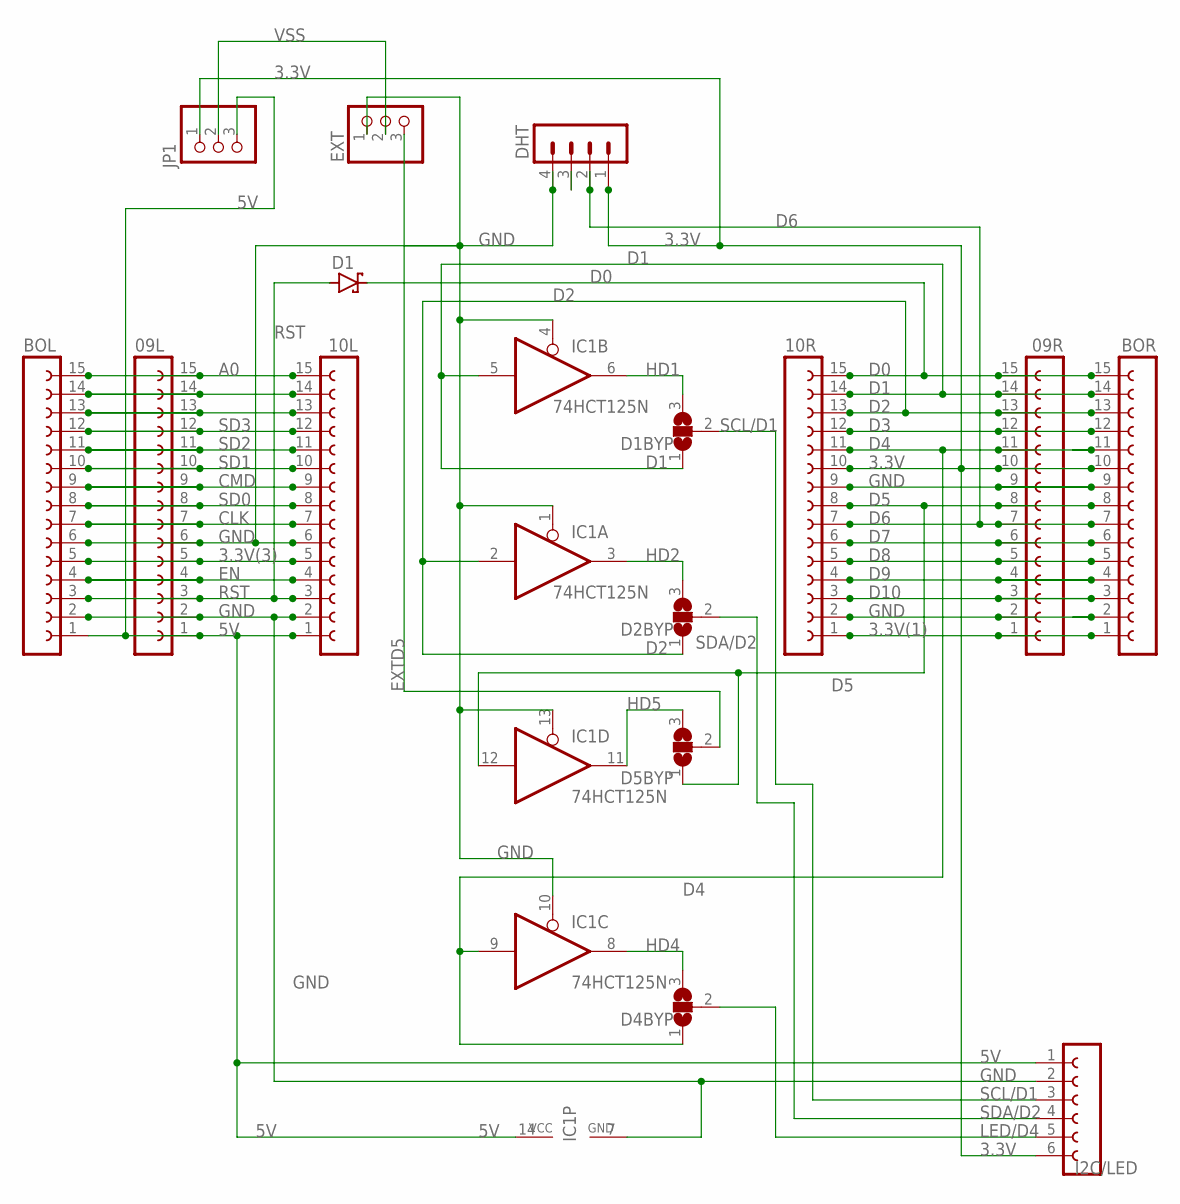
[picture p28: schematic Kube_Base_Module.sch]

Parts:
09L, 09R, 10L, 10R: 15; FE15
BOL: 15; FE15
BOR: 15; FE15
D1: BAT43; DO35-10
D1BYP, D2BYP, D4BYP, D5BYP: SJ2W; SJ_2
DHT: MA04-1
EXT: PINHD-1X3/90; 1X03/90
I2C/LED: FE06-1; FE06
IC1: 74HCT125N; DIL14
JP1: PINHD-1X3; 1X03

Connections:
3.3V: 09R.10, 10R.10, BOR.10, DHT.1, I2C/LED.6, JP1.1
3.3V(1): 09R.1, 10R.1, BOR.1
3.3V(3): 09L.5, 10L.5, BOL.5
5V: 09L.1, 10L.1, BOL.1, I2C/LED.1, IC1.14 (VCC), JP1.3
A0: 09L.15, 10L.15, BOL.15
CLK: 09L.7, 10L.7, BOL.7
CMD: 09L.9, 10L.9, BOL.9
D0: 09R.15, 10R.15, BOR.15, D1.C
D1: 09R.14, 10R.14, BOR.14, D1BYP.1, IC1.5 (I)
D2: 09R.13, 10R.13, BOR.13, D2BYP.1, IC1.2 (I)
D3: 09R.12, 10R.12, BOR.12
D4: 09R.11, 10R.11, BOR.11, D4BYP.1, IC1.9 (I)
D5: 09R.8, 10R.8, BOR.8, D5BYP.1, IC1.12 (I)
D6: 09R.7, 10R.7, BOR.7, DHT.2
D7: 09R.6, 10R.6, BOR.6
D8: 09R.5, 10R.5, BOR.5
D9: 09R.4, 10R.4, BOR.4
D10: 09R.3, 10R.3, BOR.3
EN: 09L.4, 10L.4, BOL.4
EXTD5: D5BYP.2, EXT.3
GND: 09L.2, 09L.6, 09R.2, 09R.9, 10L.2, 10L.6, 10R.2, 10R.9, BOL.2, BOL.6, BOR.2, BOR.9, DHT.4, EXT.1, I2C/LED.2, IC1.1 (OE), IC1.4 (OE), IC1.7 (GND), IC1.10 (OE), IC1.13 (OE)
HD1: D1BYP.3, IC1.6 (O)
HD2: D2BYP.3, IC1.3 (O)
HD4: D4BYP.3, IC1.8 (O)
HD5: D5BYP.3, IC1.11 (O)
LED/D4: D4BYP.2, I2C/LED.5
unnamed: 09L.14, 10L.14, BOL.14
unnamed: 09L.13, 10L.13, BOL.13
RST: 09L.3, 10L.3, BOL.3, D1.A
SCL/D1: D1BYP.2, I2C/LED.3
SD0: 09L.8, 10L.8, BOL.8
SD1: 09L.10, 10L.10, BOL.10
SD2: 09L.11, 10L.11, BOL.11
SD3: 09L.12, 10L.12, BOL.12
SDA/D2: D2BYP.2, I2C/LED.4
VSS: EXT.2, JP1.2

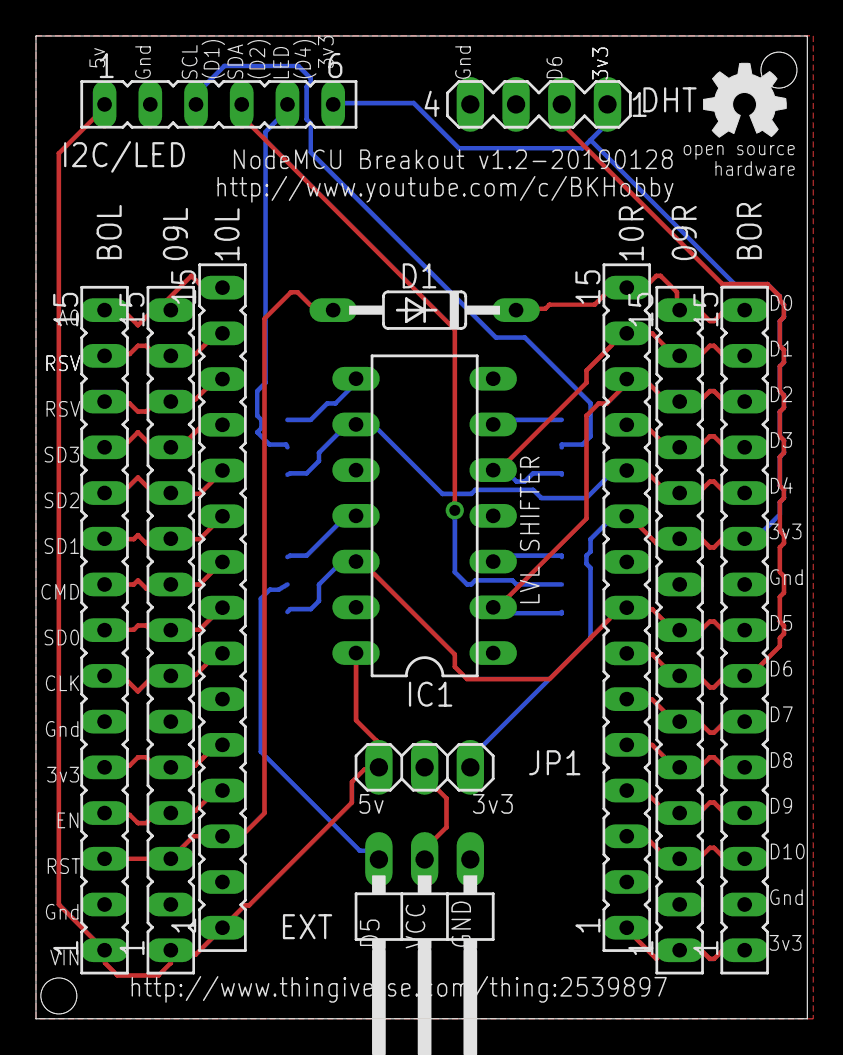
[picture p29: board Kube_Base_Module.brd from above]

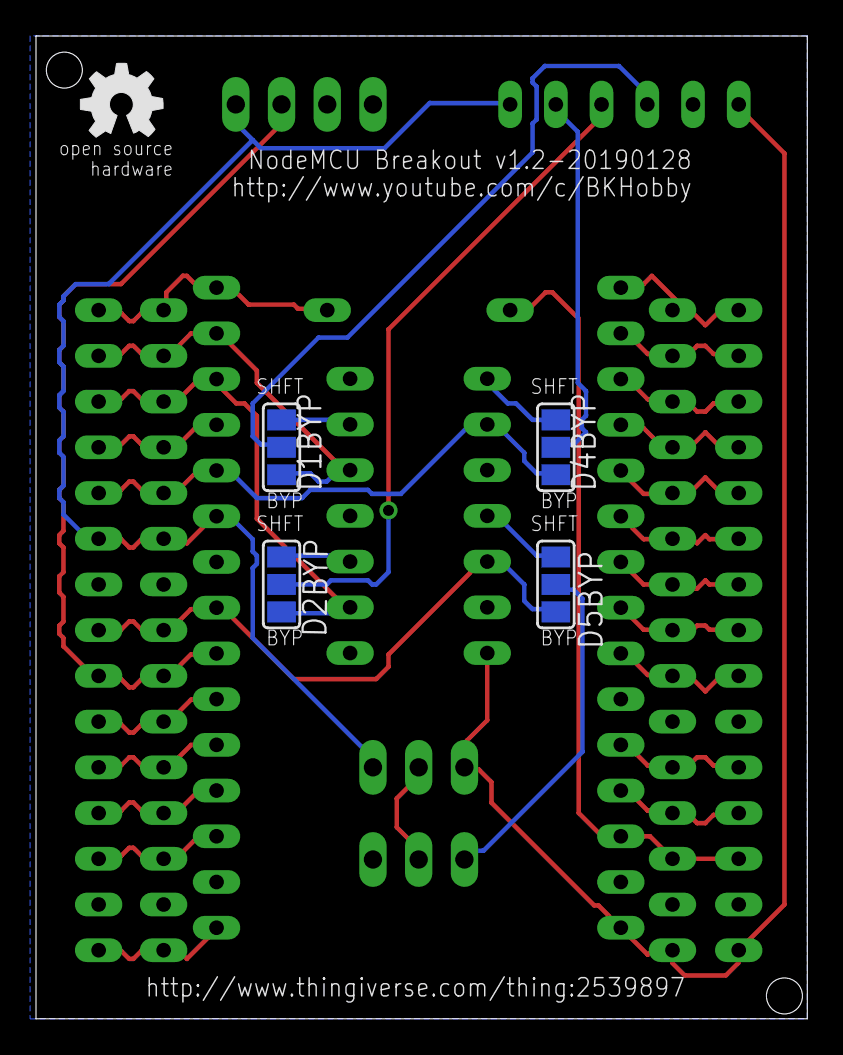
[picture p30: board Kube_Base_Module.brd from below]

Board: 2 copper layers, 42.8 x 54.6 mm, 18 parts (5 on the bottom side), 36 nets.

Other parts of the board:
U$1, U$2: OSHW_5MM

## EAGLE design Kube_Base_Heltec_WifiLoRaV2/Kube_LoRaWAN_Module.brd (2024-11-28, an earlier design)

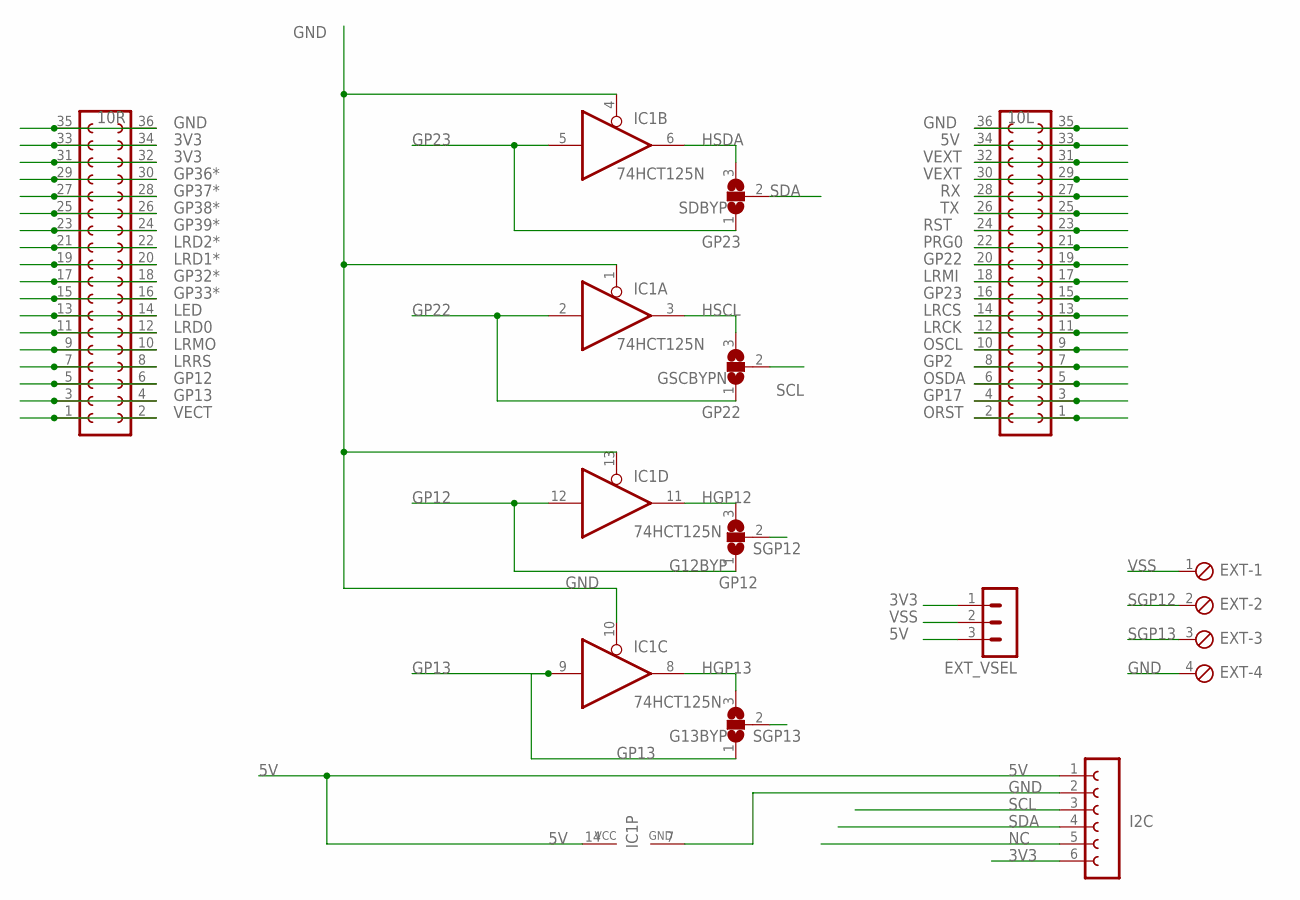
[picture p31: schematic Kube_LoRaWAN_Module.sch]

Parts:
10L, 10R: 15; FE18-2
EXT: MPT4; 4POL254
EXT_VSEL: MA03-1
G12BYP, G13BYP: SJ2W; SJ_2
GSCBYPN: SJ2W; SJ_2
I2C: FE06-1; FE06
IC1: 74HCT125N; DIL14
SDBYP: SJ2W; SJ_2

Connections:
3V3: 10R.31, 10R.32, 10R.33, 10R.34, EXT_VSEL.1, I2C.6
5V: 10L.33, 10L.34, EXT_VSEL.3, I2C.1, IC1.14 (VCC)
GND: 10L.35, 10L.36, 10R.35, 10R.36, EXT.4, I2C.2, IC1.1 (OE), IC1.4 (OE), IC1.7 (GND), IC1.10 (OE), IC1.13 (OE)
GP2: 10L.7, 10L.8
GP12: 10R.5, 10R.6, G12BYP.1, IC1.12 (I)
GP13: 10R.3, 10R.4, G13BYP.1, IC1.9 (I)
GP17: 10L.3, 10L.4
GP22: 10L.19, 10L.20, GSCBYPN.1, IC1.2 (I)
GP23: 10L.15, 10L.16, IC1.5 (I), SDBYP.1
GP32*: 10R.17, 10R.18
GP33*: 10R.15, 10R.16
GP36*: 10R.29, 10R.30
GP37*: 10R.27, 10R.28
GP38*: 10R.25, 10R.26
GP39*: 10R.23, 10R.24
HGP12: G12BYP.3, IC1.11 (O)
HGP13: G13BYP.3, IC1.8 (O)
HSCL: GSCBYPN.3, IC1.3 (O)
HSDA: IC1.6 (O), SDBYP.3
LED: 10R.13, 10R.14
LRCK: 10L.11, 10L.12
LRCS: 10L.13, 10L.14
LRD0: 10R.11, 10R.12
LRD1*: 10R.19, 10R.20
LRD2*: 10R.21, 10R.22
LRMI: 10L.17, 10L.18
LRMO: 10R.9, 10R.10
LRRS: 10R.7, 10R.8
NC: I2C.5
ORST: 10L.1, 10L.2
OSCL: 10L.9, 10L.10
OSDA: 10L.5, 10L.6
PRG0: 10L.21, 10L.22
RST: 10L.23, 10L.24
RX: 10L.27, 10L.28
SCL: GSCBYPN.2, I2C.3
SDA: I2C.4, SDBYP.2
SGP12: EXT.2, G12BYP.2
SGP13: EXT.3, G13BYP.2
TX: 10L.25, 10L.26
VECT: 10R.1, 10R.2
VEXT: 10L.29, 10L.30, 10L.31, 10L.32
VSS: EXT.1, EXT_VSEL.2

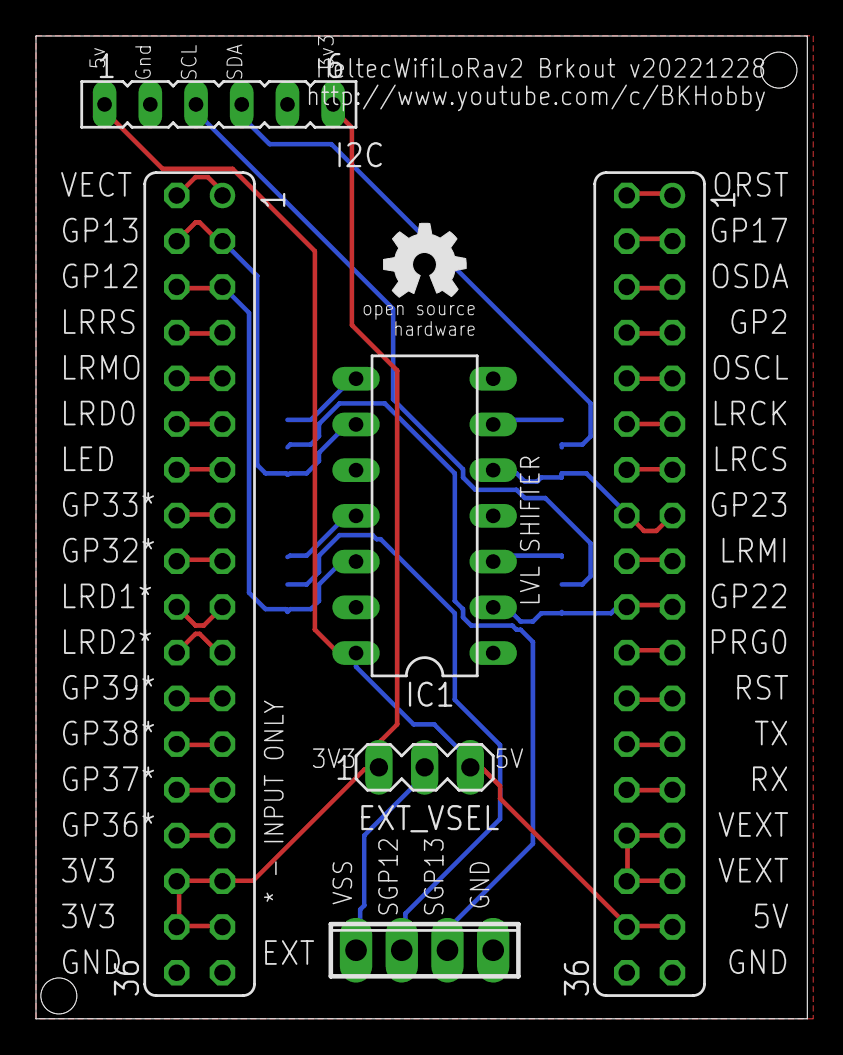
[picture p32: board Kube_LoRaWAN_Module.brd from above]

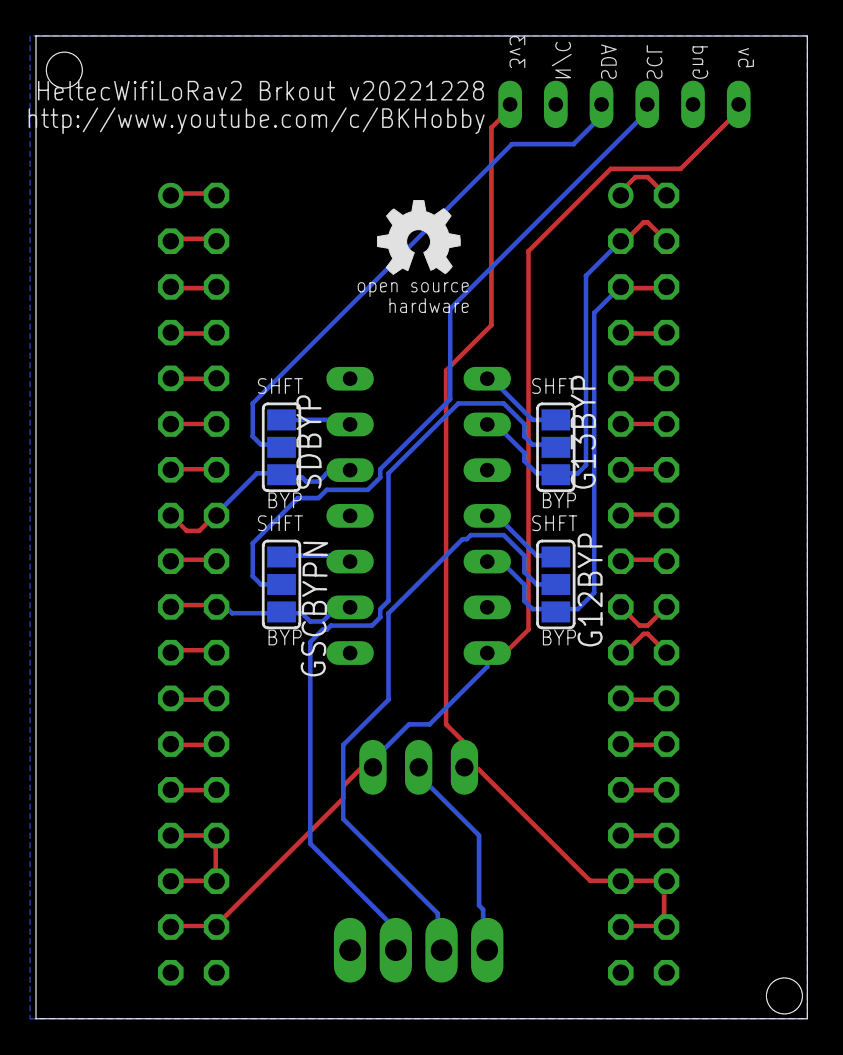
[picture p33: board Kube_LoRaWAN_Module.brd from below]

Board: 2 copper layers, 42.8 x 54.6 mm, 12 parts (5 on the bottom side), 42 nets.

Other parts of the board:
U$1, U$2: OSHW_5MM

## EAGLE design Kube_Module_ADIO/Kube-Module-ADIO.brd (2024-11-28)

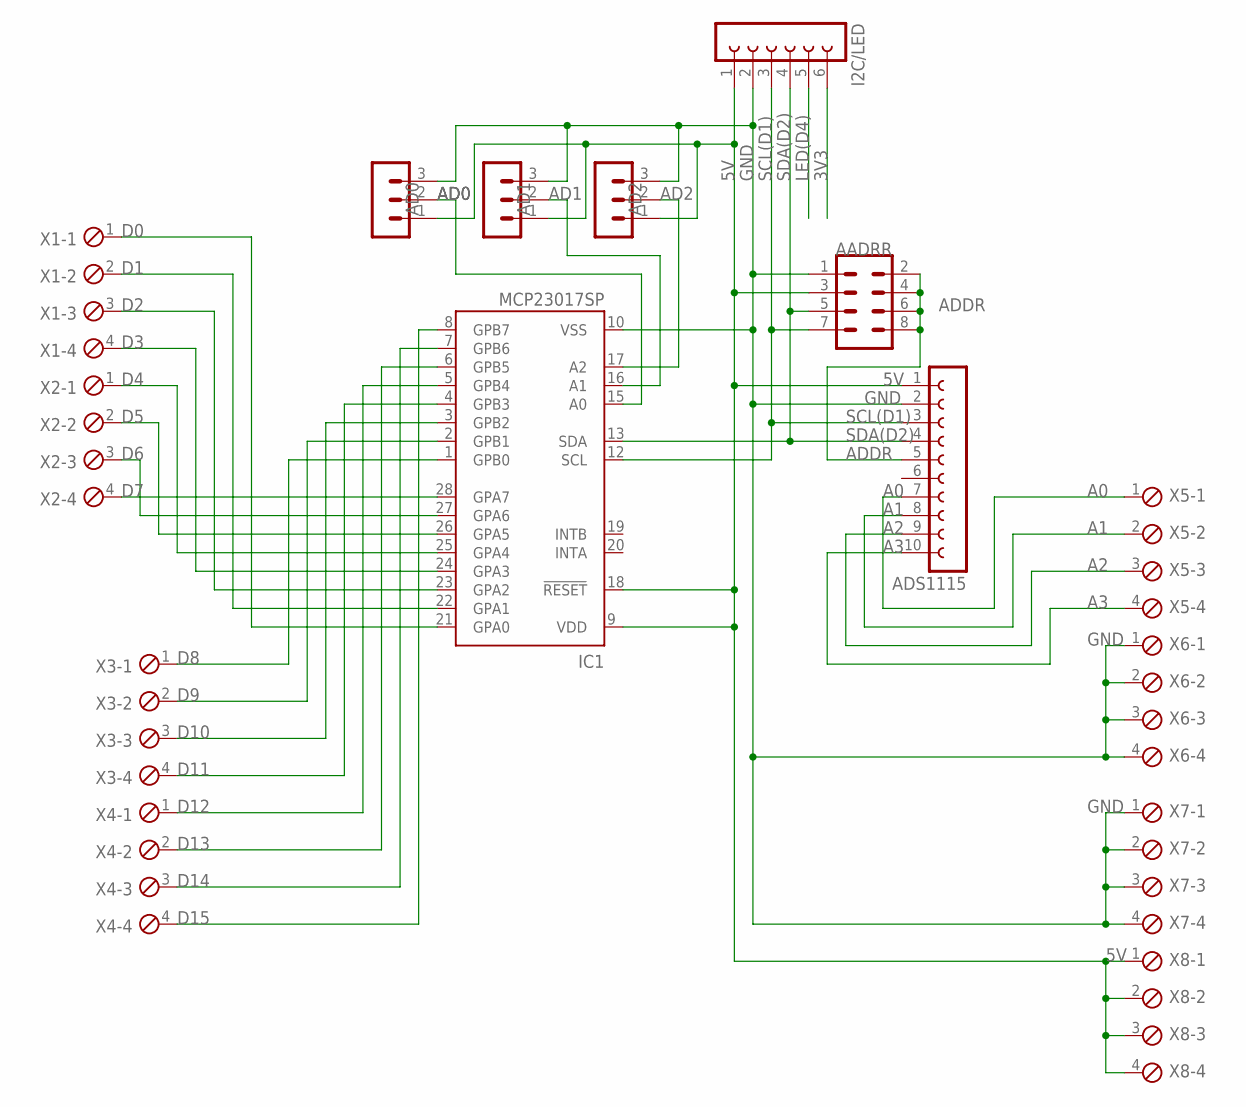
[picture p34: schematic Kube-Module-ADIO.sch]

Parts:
AADRR: MA04-2
AD0, AD1, AD2: MA03-1
ADS1115: FE10W
I2C/LED: FE06-1; FE06
IC1: MCP23017SP; DIL28-3
X1, X2, X3, X4, X5, X6, X7, X8: MPT4; 4POL254

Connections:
3V3: I2C/LED.6
5V: AADRR.3, AD0.1, AD1.1, AD2.1, ADS1115.1, I2C/LED.1, IC1.9 (VDD), IC1.18 (!RESET), X8.1, X8.2, X8.3, X8.4
A0: ADS1115.7, X5.1
A1: ADS1115.8, X5.2
A2: ADS1115.9, X5.3
A3: ADS1115.10, X5.4
AD0: AD0.2, IC1.15 (A0)
AD1: AD1.2, IC1.16 (A1)
AD2: AD2.2, IC1.17 (A2)
ADDR: AADRR.2, AADRR.4, AADRR.6, AADRR.8, ADS1115.5
D0: IC1.21 (GPA0), X1.1
D1: IC1.22 (GPA1), X1.2
D2: IC1.23 (GPA2), X1.3
D3: IC1.24 (GPA3), X1.4
D4: IC1.25 (GPA4), X2.1
D5: IC1.26 (GPA5), X2.2
D6: IC1.27 (GPA6), X2.3
D7: IC1.28 (GPA7), X2.4
D8: IC1.1 (GPB0), X3.1
D9: IC1.2 (GPB1), X3.2
D10: IC1.3 (GPB2), X3.3
D11: IC1.4 (GPB3), X3.4
D12: IC1.5 (GPB4), X4.1
D13: IC1.6 (GPB5), X4.2
D14: IC1.7 (GPB6), X4.3
D15: IC1.8 (GPB7), X4.4
GND: AADRR.1, AD0.3, AD1.3, AD2.3, ADS1115.2, I2C/LED.2, IC1.10 (VSS), X6.1, X6.2, X6.3, X6.4, X7.1, X7.2, X7.3, X7.4
LED(D4): I2C/LED.5
SCL(D1): AADRR.7, ADS1115.3, I2C/LED.3, IC1.12 (SCL)
SDA(D2): AADRR.5, ADS1115.4, I2C/LED.4, IC1.13 (SDA)

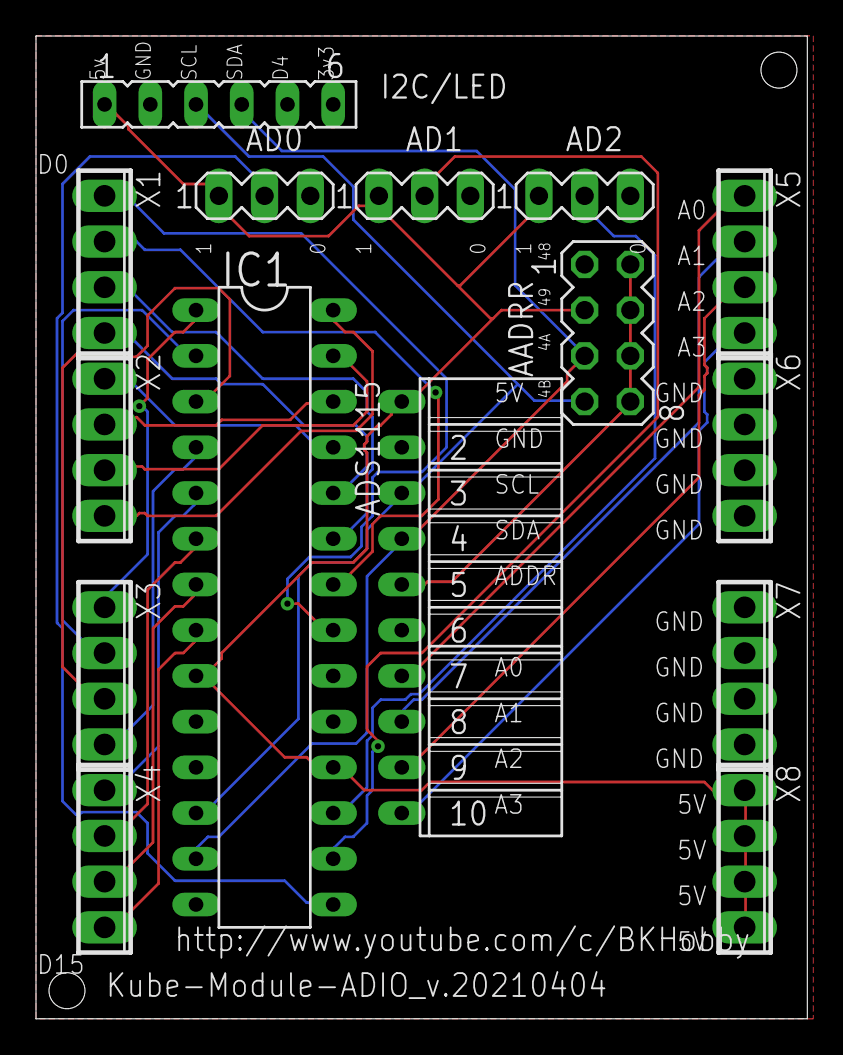
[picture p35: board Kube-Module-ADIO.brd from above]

Board: 2 copper layers, 42.8 x 54.6 mm, 15 parts (0 on the bottom side), 28 nets.

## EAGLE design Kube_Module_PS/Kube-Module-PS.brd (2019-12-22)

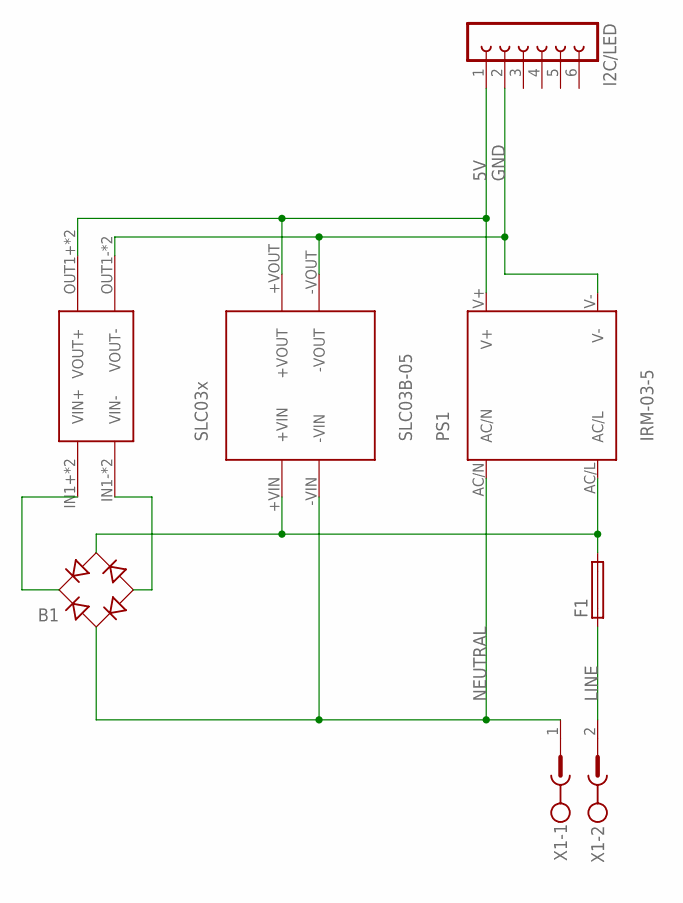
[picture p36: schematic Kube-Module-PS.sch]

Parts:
B1: RB1A
F1: LITTLEFUSE
I2C/LED: FE06-1; FE06
MP1584: MP1584; DC-BRICK
PS1: IRM-03-5; IRM_03
SLC03X: SLC03B-05; SLC03X
X1: MSTBV2

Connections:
5V: I2C/LED.1, MP1584.OUT1+ (VOUT+), MP1584.OUT2+ (VOUT+), PS1.V+, SLC03X.+VOUT
GND: I2C/LED.2, MP1584.OUT1- (VOUT-), MP1584.OUT2- (VOUT-), PS1.V-, SLC03X.-VOUT
LINE: F1.1, X1.2
LINE-FUSED: B1.AC2, F1.2, PS1.AC/L, SLC03X.+VIN
NEUTRAL: B1.AC1, PS1.AC/N, SLC03X.-VIN, X1.1
V+: B1.+, MP1584.IN1+ (VIN+), MP1584.IN2+ (VIN+)
V-: B1.-, MP1584.IN1- (VIN-), MP1584.IN2- (VIN-)

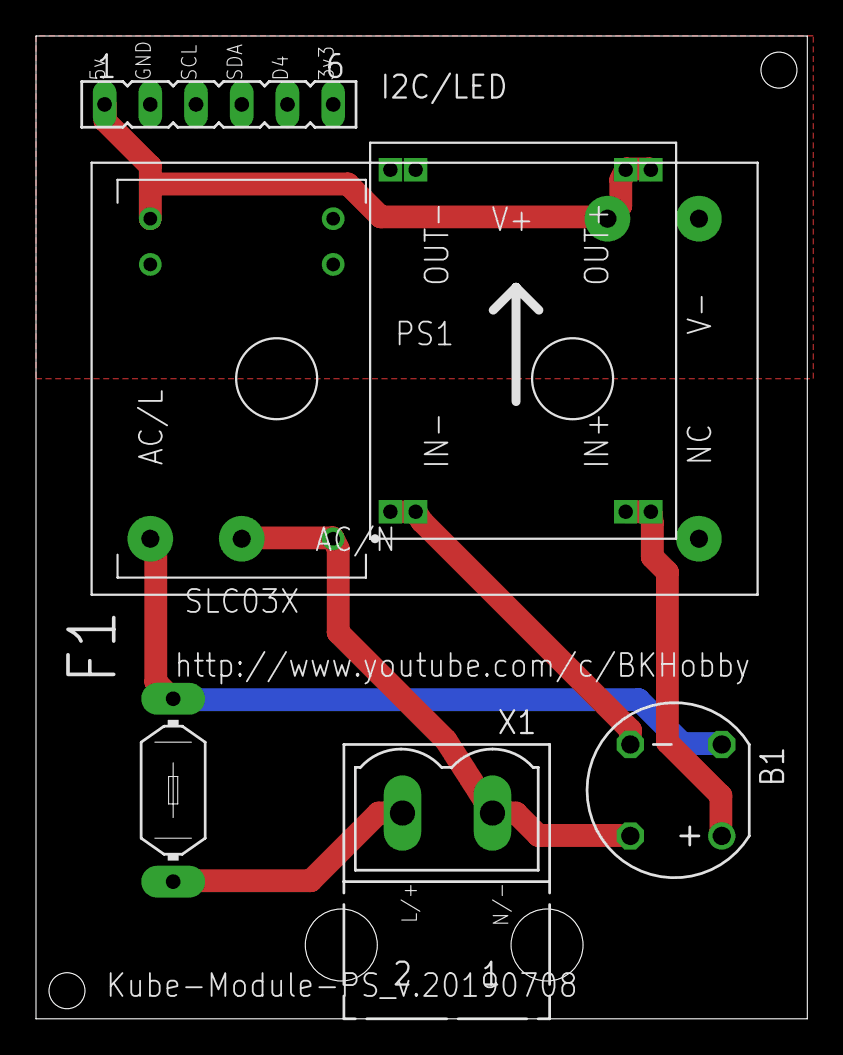
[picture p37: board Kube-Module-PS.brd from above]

Board: 2 copper layers, 42.8 x 54.6 mm, 7 parts (0 on the bottom side), 7 nets.

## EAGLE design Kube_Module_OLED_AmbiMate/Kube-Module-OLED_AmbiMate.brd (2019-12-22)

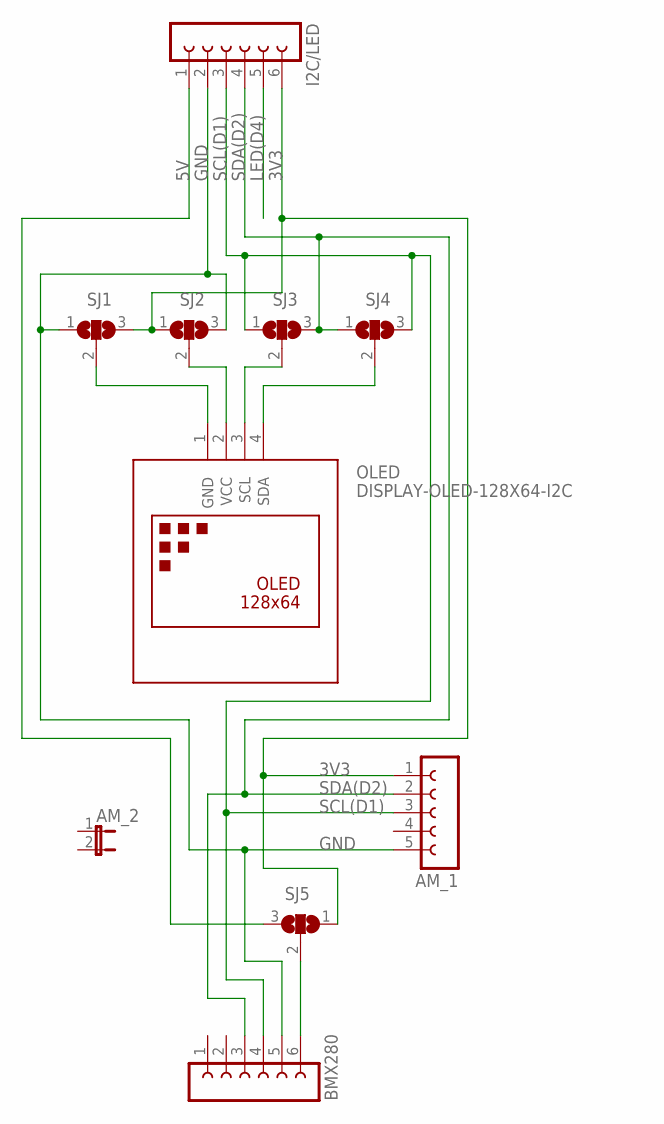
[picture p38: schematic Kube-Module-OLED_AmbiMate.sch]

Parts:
AM_1: FE05-1
AM_2: JP1E; JP1
BMX280: FE06-1; FE06
I2C/LED: FE06-1; FE06
OLED: DISPLAY-OLED-128X64-I2C
SJ1, SJ2, SJ3, SJ4, SJ5: SJ2W; SJ_2

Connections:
3V3: AM_1.1, I2C/LED.6, SJ1.3, SJ2.1, SJ5.1
5V: I2C/LED.1, SJ5.3
BMX_VCC: BMX280.6, SJ5.2
GND: AM_1.5, BMX280.5, I2C/LED.2, SJ1.1, SJ2.3
LED(D4): I2C/LED.5
OP1: OLED.1 (GND), SJ1.2
OP2: OLED.2 (VCC), SJ2.2
OP3: OLED.3 (SCL), SJ3.2
OP4: OLED.4 (SDA), SJ4.2
SCL(D1): AM_1.3, BMX280.4, I2C/LED.3, SJ3.1, SJ4.3
SDA(D2): AM_1.2, BMX280.3, I2C/LED.4, SJ3.3, SJ4.1

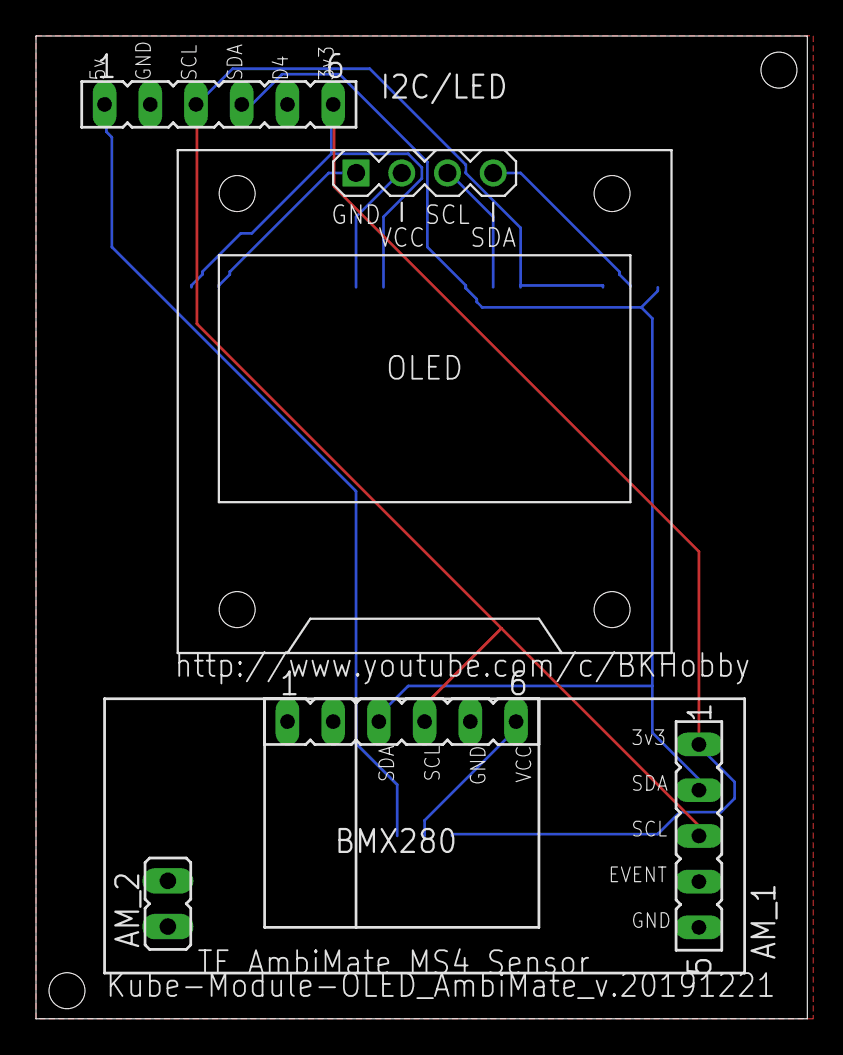
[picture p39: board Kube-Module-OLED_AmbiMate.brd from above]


Board: 2 copper layers, 42.8 x 54.6 mm, 10 parts (5 on the bottom side), 10 nets.

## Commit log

2019-07-09 Initial Upload
    [Kube-Module-ADIO.brd, Kube-Module-ADIO.sch, Kube-Module-OLED_AmbiMate.brd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]
2019-07-09 Adding 3d models for the Base module, back cover and OLED submodule
    [Kube_Base_Module_Enclosure.stl, Kube_Base_Module_Enclosure_Cover.stl, Kube_Module_OLED_AmbiMate.stl]
2019-07-11 Adding Gerber files, gitignore and new Readme
    [copper_bottom.gbr, copper_top.gbr, drills.xln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]
2019-07-13 Added some board definition paragraphs/pictures.
2019-07-14 More changes to Readme, regenerated ADIO Gerbers
    [drills.xln, gerber_job.gbrjob]
2019-07-25 Mods to ADIO to add add'l GND pins and space TBs better.
    [Kube-Module-ADIO.brd, Kube-Module-ADIO.sch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]
2019-07-25 Mods to OLED board to get rid of EVENT_OUT (causes boot issues since D4 needs to be held HI)
    [Kube-Module-OLED_AmbiMate.brd, Kube-Module-OLED_AmbiMate.sch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]
2019-07-25 Fixed schematics
2019-08-03 All updated STLs, and ADIO board with tb fixes.
    [Kube-Module-ADIO.stl, Kube-Module-OLED_AmbiMate.brd, Kube-Module-PSU.stl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]
2019-12-22 Added BMx280 sensor to OLED Board
    [Kube-Module-OLED_AmbiMate.brd, Kube-Module-OLED_AmbiMate.sch, Kube-Module-PS.brd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]
2019-12-22 Updated readme for OLED changes, new PCB renders
2020-04-25 Adding Fusion360 files for all modules
    [Enclosure-Base.f3d, Enclosure-Rear-Cover.f3d, Kube-Module-Enclosure-Submodule-OLED.f3z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]
2021-04-05 Added ADS1115 addressing jumper
    [Kube-Module-ADIO.brd, Kube-Module-ADIO.sch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]
2021-04-05 Added LoRaWan (Heltec) board
    [Enclosure-Rear-Cover.f3d, Kube_LoRaWAN_Module.brd, Kube_LoRaWAN_Module.sch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]
2024-11-28 11/28/2024(BK): Merging all changes on remote
    [Enclosure-Base.f3d, Enclosure-ESP32HLG.f3d, Enclosure-LoRaWAN.f3d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]

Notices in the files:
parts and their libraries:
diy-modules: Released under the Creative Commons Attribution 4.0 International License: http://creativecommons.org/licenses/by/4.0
